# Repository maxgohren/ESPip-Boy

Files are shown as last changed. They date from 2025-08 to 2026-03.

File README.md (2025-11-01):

# ESPip-Boy
A smart watch based on the ESP32

# Features
* ESP32 MCU with full Bluetooth Classic
* SD Card storage
* TFT RGB Display
* Flashlight
* Microphone
* Sensors
  * Heart Rate & Blood Oxygen
  * Light Sensor (Auto Display Brightness)
  * Accelerometer (Auto Wakeup, Gestures) 
  * Magnetometer  (Compass)
* Controlled with Push-Button Rotary Encoder

# Planned Applications
* Compass
* Pedometer
* Map/Photo Display
* Clock
* Heart Rate Monitor
* Music Playback
* Bluetooth Manager
* System Monitor (CPU Tasks, SD Storage, RAM Usage etc.)

Powered by a LiPo, charged and programmed over USB

# V1.0 PCB Complete

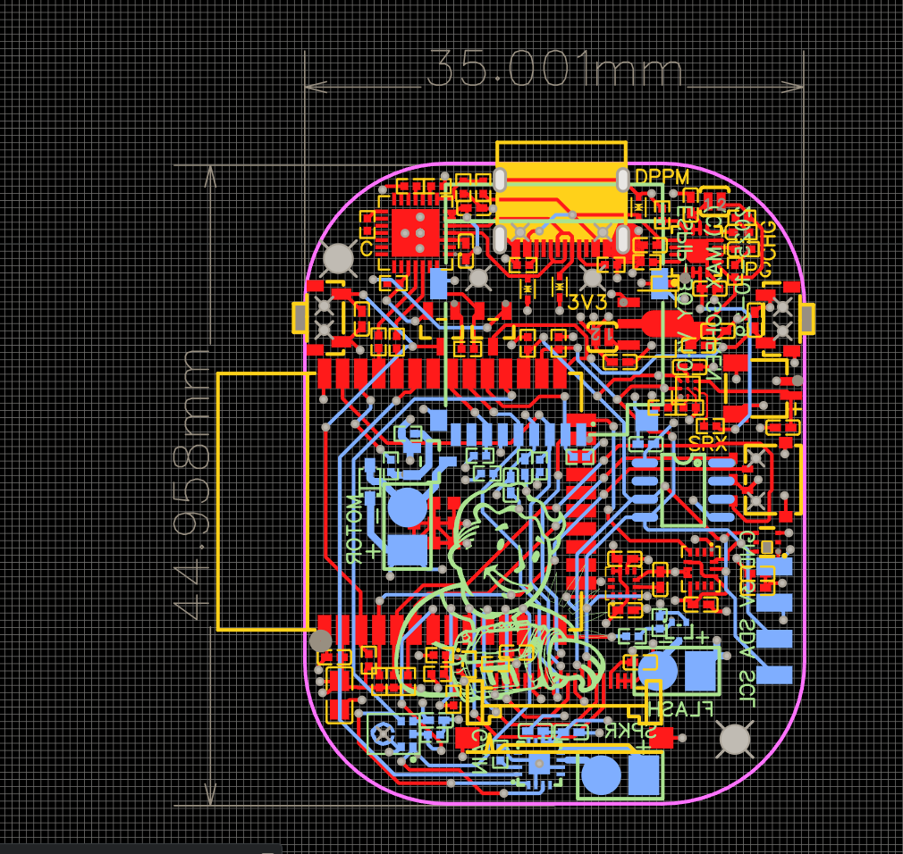
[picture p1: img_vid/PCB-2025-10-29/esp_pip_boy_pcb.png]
PCB Photo

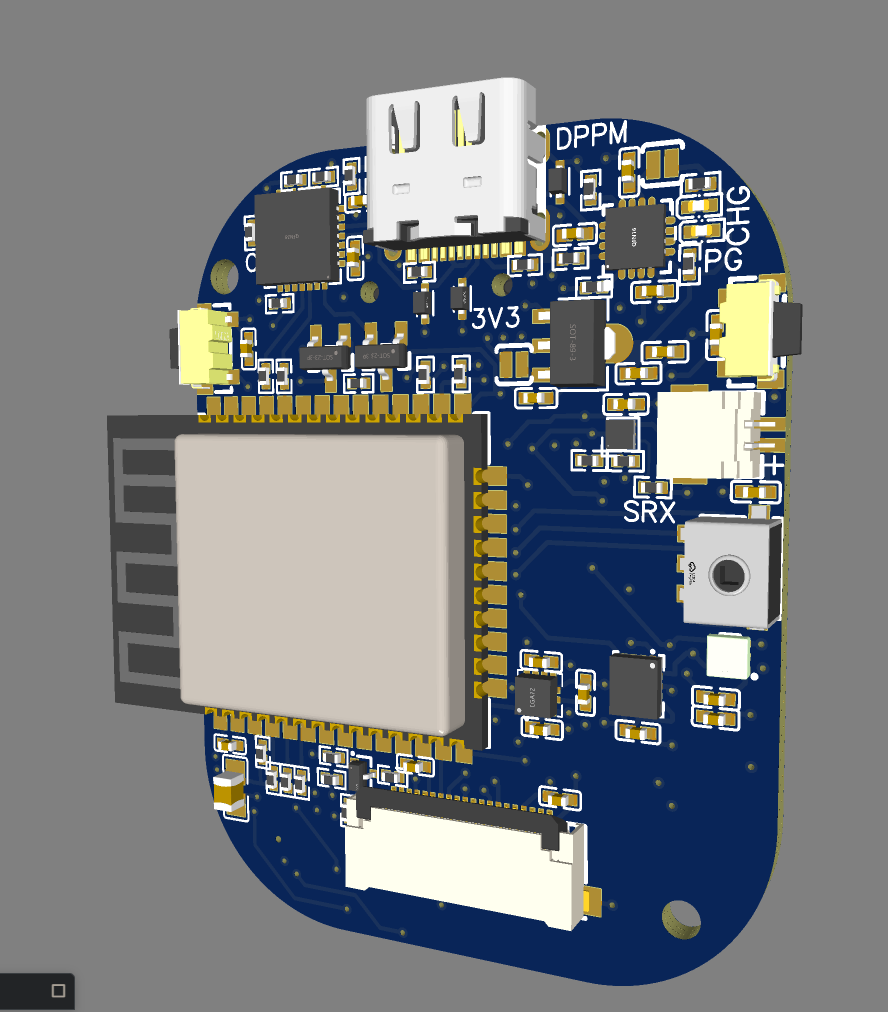
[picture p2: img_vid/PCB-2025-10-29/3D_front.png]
3D Front

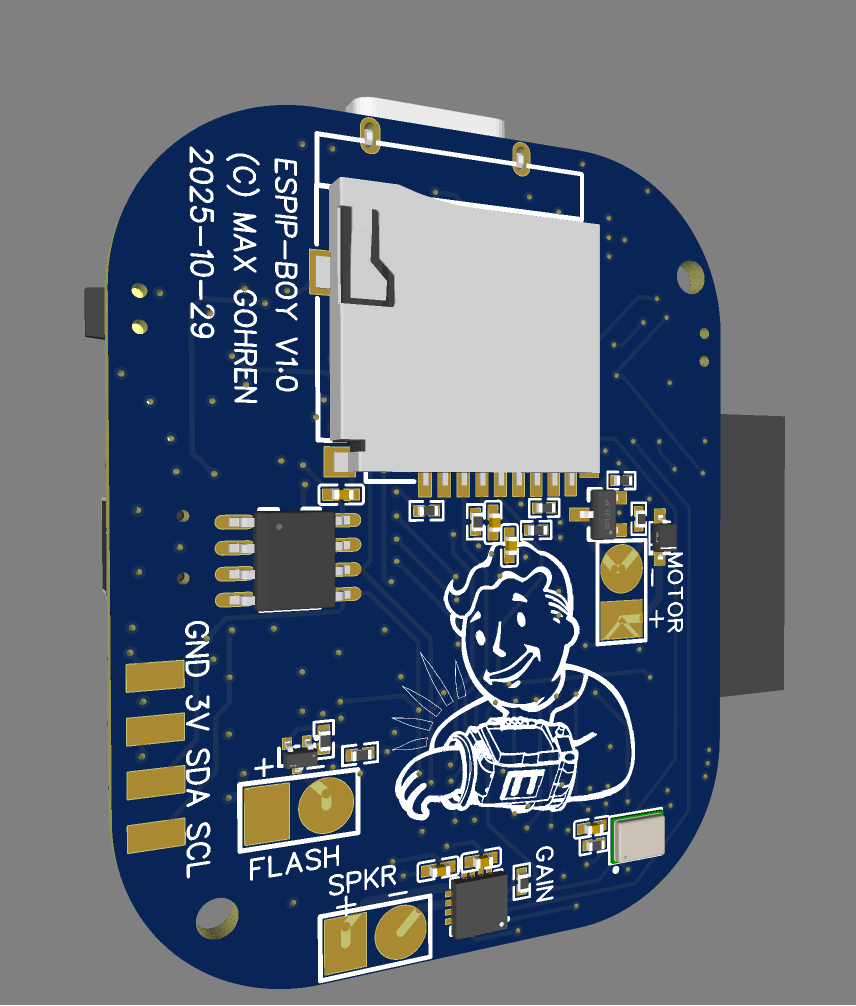
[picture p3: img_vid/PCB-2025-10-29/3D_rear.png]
3D Rear


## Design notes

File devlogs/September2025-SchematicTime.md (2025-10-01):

# September 30 2025 - Tuesday 11:41 PM
Audio recording works!

I've tried a handful of times on seperate occasions to record my microphone
output to a WAV file and write it to the SD Card. I've tried github examples,
built in examples and nothing has worked so far. I gave up on trying other
people's code, so I just got ChatGPT to write me the simplest example to do it.

Surprise surprise, it works great! And the code is so easy to understand,
organized in only one file so debugging is super easy. Other's used elaborate
wrappers on SD card libraries, made me use PlatformIO in VSCode, but never
actually got me a working product.

It is bittersweet though, it makes me feel as if I couldn't have done it
without ChatGPT. The truth is I can though, I would have ended up with
a similar solution anyways:
I would have taken the SD card library that has worked for me, and taken
Atomic14's I2S microphone example (which outputs just to the serial plotter), 
and combine them so that I have working mic + SD card. It is true I didn't do
this, and I haven't truly learned the I2S interface as well as I would like.

However, I can still, and I will, write my own implementation to at least
understand the calling of the different I2S functions, decrementing sample
counts and so on and so forth. 

Another development goal complete!

# September 25 2025 - Thursday  9:31 PM
Too many I2C devices!

0x15 -> CST816S Touchscreen Controller
0x19 -> LSM303 Accelerometer
0x1E -> HMC5883 Magnetometer
0x23 -> BH1750 Light Sensor

0x57 -> MAX30102 Heart Rate / Blood Oxygen Sensor
0x68 -> MPU6050 

0x57 -> DS3231 EEPROM Chip (AT24C32)
0x68 -> DS3231 RTC

Finally got the fake MAX17043 battery fuel gauge working, but it's terribly
wrong. Needed to ground the QST pin to get it recognized on the I2C bus, and
then got a reading of 12% when the battery had a voltage of ~3.7V haha. It's
easy enough to design around that I'm not concerned about not having it
working. 

I'm very excited, most of my prototyping is finished, and there are no more
parts I want to add. I've tested the USB input and charging the battery while
powering the load with the charger (I still may use the battery disconnect
circuit, it's only 2 components), and the microphone is working but I haven't
actually listened to the output yet. 

Almost done the breadboard prototype!
# September 24 2025 - Wednesday 10:43 PM
Got the speaker and the microphone working seperately again.

Speaker crackling issue? Was just the volume set too high! I turned it down the
audio was crystal clear at lower volumes, no crackling at all. Will have to
dial this in before production as gain is controlled through pulling the gain
pin high or low. 

The microphone is working again but confusing me. Using 
[atomic14's mic test](https://github.com/atomic14/esp32-i2s-mic-test/blob/main/README.md) I can only get the mic working when I use only the RIGHT channel of audio, even though I have the L/R pin pulled low. This confuses me as the [INMP441 datasheet](http://invensense.tdk.com/wp-content/uploads/2015/02/INMP441.pdf) says it only ooutputs to the right channel when the L/R pin is pulled low. Bizarre!

Now I am working on recording a sound clip to test the audio quality of the
microphone :).

# September 18 2025 - Thursday 12:16 AM
Got my audio equipment in today! A MAX98357 audio dac + amplifier combo (the IC
is so tiny haha) and a couple speakers, one I am currently trying is only 16
x 9 mm! And is quite loud!

I hooked it up and got some Gavin Adcock playing right away! It is very easy to
use, and I owe a huge thanks to [pschatzmann](https://github.com/pschatzmann),
his Arduino libraries are TOP NOTCH!

I do have a problem though, the audio is full of pops and crackle. I tried some
online troubleshooting which included adding some filtering caps at the power
supply, trying different power supplies, and changing the gain level, but
nothing seems to help. I am happy anyways to now have a working audio
interface, albeit a noisy one :).

# September 13 2025 - Saturday 11:44 AM
"It just works". It actually just works! LVGL with Arduino GFX + TouchLib
works! I still had to do the quirky include path editing and moving the demo
folder to make a demo work, but it works! No crazy colour bugs, no rotation
issues, no mismatch betwen coord systems between display and touch, it just
works!

I do have crashing on the button matrix, but a more complicated button matrix
with a scrolling view area works haha. I am very happy. The display is very
responsive and the LVGL grapics work just like they look on the examples. 

OMG the music player demo is sooo sick. The animations are actually pretty
smooth and the layout is perfect (aside from touchscreen bounds not being
dialed in, I can't exit a menu because the touchscreen bounds are smaller than
the drawn button bounds). 

Really satisfied with today's work and graphics setup. Really all there is to
do now, is implement a simple menu with one of the various widgets (and
hopefully one that doesn't crash) and then implement simple test apps for heart
rate, clock, etc. 

Then, when that is done, some sleep and interrupt handling on touch and motion. 

And then when our proof of concept is finished, were good to finalize the
design and properly finish the schematic, knowing the design works :).

https://github.com/user-attachments/assets/a17e04a2-b65c-40f8-9db9-b9d96eed87ed

# September 13 2025 - Saturday 12:54 AM
The new breadboard is off to an amazing start. All 6! i2C sensors enabled and
detected on i2c scan. Capacitive touch sensor working perfectly and very
responsively. Display working perfectly on test sketch. 

I am so happy it works. 20 pins later haha. I was scared to death too, because
I accidentally wired it up the wrong way after spending so long learning about
current limiting resistors and checking a million schematics to make sure
I wouldn't blow my backlight. Turns out I could smell how hot my touch
controller was, because I thought I was wiring up the display, but I was
actually wiring up the touch controller as my FPC breakout was flipped around.

I was using the silkscreen markings for the bottom side, not the side I was
actually connected to, on the 2 layer breakout board!

Even though my touch controller got super hot, I'm super happy it still works.
Here's to almost finishing a very clean prototype! Only a few more components
are in the mail, and then it's time to call it done, and start serious design
work on the PCB!

It was cleaner before the display

# September 11 2025 - Thursday 10:33 PM
Today I am taking a break from display software, to work on display hardware!

I got my new touchscreen TFT IPS display in, the same 1.69" I was using before
but not touchscreen. I am traumatized from my day spent with my resistive touch
2.4" and LVGL. 

I also got some new jumpers, breadboard and buck-boost power supply convertors
so my I actually ripped my whole breadboard clean and will rebuild it bigger,
better, faster, stronger in the coming days. My design is more finalized so
I figured it is time to clean it up to help in debugging and schematic design. 

I spent tonight tinkering with the new display and reading about backlight LED
current limiting resistors as I don't want to burn my only one out. If I do,
it's ok but I'd rather not wait another 2 weeks and another $12 for another
one. Looks like the reference schematics, my own model and some reading point
to resistors in the ~1-100 Ohm range, as the backlight drops 3.2V. For a 3.3V
supply, this leaves 0.1 V for the resistor. Limit it to 60 mA, gives you
a solid 1.7 Ohms, or a more conservative 40 mA for 2.5 Ohms. I'll use 10 and go
from there. 

Gonna take a break now. I have a habit of pouring so much time into this
project that it becomes stressful, with poor focus and fatigue being the
driving factors. I want more quality, less quantity. Looking forward to the new
display and the cleaner breadboard setup. Hopefully that inspires LVGL and my
touchscreen to work flawlessly together!

# September 10 2025 - Wednesday 11:47 PM
OMG LVGL is kind of a nightmare. 

I have been at it all day. Installing my touchscreen display, trying out more
examples and demos, finally comfortably using a slider widget, trying Arduino
IDE in WSL to improve horrendous build times, it's been the worst integration
into this project so far. 

The last headache (I hope it's the last) has been the touchscreen functionality
with TFT_eSPI and LVGL. I've found many threads complaing about how the
touchscreen seems to rotate completely opposite the display so it never lines up
correctly.

https://forum.lvgl.io/t/screen-rotation/19316/12
https://github.com/lvgl/lvgl/issues/7841
https://forum.lvgl.io/t/inconsistency-between-display-rotation-and-touchscreen-coordinate-rotation/20242

I've been trying solutions posted and playing with swapping coordinates around
but no success. I don't really understand what's happening under the hood, who
rotates what where, and how many times and which direction things are getting
rotated. I need to do some more experiments to see which rotations from which
libraries are required when. 

Thankfully I only need one orientation, I hope that may make this easier. But
man has this been a difficult ride.

# September 10 2025 - Wednesday 01:06 AM
Man LVGL is not simple to use. Manual install of folders to different locations
in the library. Copy the config to the libraries folder. Compile and get the
hello world running ok? Now try the demos, that in order to get it to just
barely work (it doesn't seem to respond to my choice of demo from the
		aformentioned config file) I need to manually massage a relative include
path of a header. WTF?

The one thing keeping me going right now is this demo of a smartwatch
[UI](https://lvgl.io/demos). It looks so amazing, I really hope I can get this
stable and working!

Time for bed now though, I am happy I got my demo working when this morning I
could only get the Hello World working.

# September  9 2025 - Tuesday 09:50 AM
Waiting for hardware. Stuck on power supply choices. Simple discrete components
linked together or a powerful PMIC with everything but the kitchen sink? I do
not like making schematics for components I don't have a working reference
design for right in front of me. I check JLC PCBA costs, and right out of the
gate my design, without any cost optimizations, will be $200 for two boards.
Pretty crazy.

I would then not like to experiment with new components I am not comfortable
with as this price drastically reduces the amount of hardware revisions I would
like to do. Instead, if I would like to use the cheap but ubiquitous AXP2101
with multiple bucks and LDOs, along with an integrated LiPo charger and fuel
gauge, I will order it on AliExpress along with a breakout board. This will
satisfy my need to have a working demo before I try to make a schematic
including it. 

It will be a parallel development/prototype with both a discrete setup (MAX17048
		Fuel Gauge + TP63020 buck-boost 3.3V supply + TP4056/DW01
		charger/protection) and an  integrated PMIC solution - AXP2101. Having a
working prototype will allow me to learn about the devices and have real world
measurements on how they perform in best and worst case battery life scenarios. 

No more endless document reading, get your hands dirty and see what works!

While waiting for the aformentioned hardware, I am working on LVGL integration.
It is the best solution for my graphic needs and looks amazing. I got the hello
world demo today, but man the examples/demo work is so annoying, they have this
requirement you copy the examples or demo folders into the src/ folder but it
always throws an error. It can't find the actual src, which according to the
include directives is in the place it would be if I never copied the demo folder
in the first place! So confusing, I will try again later!

# September  6 2025 - Saturday 12:36 AM
Today on my schematic, I wired up the display, the microphone and some roughed-in enable pins for
my various high power peripherals like my vibration motor, buzzer and speaker. I
did this so that I can see how many pins I have available and if my design is
going to all fit on the ESP32's GPIO selection. So far I think it will be okay,
and it will be helped if I can select a great PMIC with some I2C
selectable outputs. This would allow me to have more I2C control instead
of GPIO control which I am lacking. I really don't need the power of a
GPIO anyways for simple enable pins, but for stuff like vibration motors
or buzzers I do need a PWM output. All part of the balancing act haha.

I've asked ChatGPT a bunch of times for my perfect PMIC and it keeps
landing on the same modules, the MAX77658 and the TI BQ25190. Both are
great chips and both do what I need. I haven't yet narrowed it down, but I
would like to as it will influence the GPIO bottleneck and overall design.

I'm aiming at the following power path:
3.7V lipo -> buck boost @ 3.5V -> LDO @ 3.3V.
I'm weary of these PMICs and using the buck boost output to directly power my
ESP32 as the LDOs are more for the audio/RF paths, but I need the power spike
handling ability. I will read more about ripple and how the ESP32 handles it.

I'm really happy to have done more experimenting with the power supply and
found why I need what I need. Running the battery straight into the 3.3V
actually works and doesn't fry anything. This of course means my
aliexpress LDO is not rated high enough for the BT/WiFi spike. I would
like to try some bigger caps across the output to see if that helps. I've
got a big 220uF right here, but it's late.

I've made another order of parts like a buck-boost convertor, touch screen
and breadboard. I've also got a cart full of audio supplies like a MAX
mono amp and a small selection of tiny speakers. When these components
come in, I will (for the 15th time) be done prototyping haha. Well, I just
want it all working on a single board with all the devices connected so
that there are no suprises when the PCB comes in. I don't want to find out
theres another 500mA current spike somewhere and not have the hardware to
deal with it. 

LETSSS GOOOO!!!

# September  3 2025 - Wednesday  6:39 PM
It's been non-stop schematic time. Pouring over datasheets and reading
requirements to find the perfect components. I have almost finished this quest.
The last beast to slay, and the most important one, is the power management.
I want a complex system right now, and that may need to change:
* LiPo Battery Charging
* Battery Protection
* Battery Fuel Gauge
* Buck Convertor for ESP32 and display
* LDO for Audio and RF

I have found many suitable PMICs that have these requirements, but I am not
sure if I want to have this level of complexity. Part of me, just to keep it
simple, wants to do LiPo -> TP4056 -> 3.3V LDO -> power whole system. If
I can't decide or commit to a real PMIC, this discrete solution will work
perfectly fine :). Here's to knocking out the last of the part selection so
that the schematic can be finished and fine-tuned.

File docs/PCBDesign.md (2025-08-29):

# When finished assembly
* Check for shorts on all SMT components
* Check for shorts between chips and power rails
# Before Ordering
* No DRC errors of course
* Manully check each component and circuit on the board to make sure it was wired correctly
# USB
USB 2.0 spec defines a differential characteristic impedance of 90 ohms, +/- 15%.
[Controlled Impedance PCB Layer Stackup- JLCPCB](https://jlcpcb.com/impedance)
https://jlcpcb.com/pcb-impedance-calculator
https://docs.espressif.com/projects/esp-dev-kits/en/latest/esp32s3/esp32-s3-usb-bridge/user_guide.html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
https://dubiouscreations.com/2021/04/06/designing-with-usb-c-lessons-learned/
# Standard 
Changing all signal tracks to 6 mil for 60 Ohms, increasing space between tracks as well.
All power tracks not in polygons are 21 mil
# Copper Polygons
Surround power paths with copper fills (polygons) to lower resistance and give power an easier time to flow.
# Design Notes
* Start with an existing schematic and adapt it to your needs (like all learning)
* Thicker traces for power traces, thinner for signal
* Never go to minimum trace width/spacing -> you are increasing crosstalk
* Space traces 3 * tracewidth from each other
* Don't put silkscreen on vias or pads, it will not print on copper -> can tent vias to be able to print on them

## ESP32 Flash and PSRAM Design Guidelines
[PCB Layout Design - ESP32 - — ESP Hardware Design Guidelines latest documentation](https://docs.espressif.com/projects/esp-hardware-design-guidelines/en/latest/esp32/pcb-layout-design.html)
[esp32-sche-core.png (1602×816)](https://docs.espressif.com/projects/esp-hardware-design-guidelines/en/latest/esp32/_images/esp32-sche-core.png)
https://docs.espressif.com/projects/esp-hardware-design-guidelines/en/latest/esp32/schematic-checklist.html

# Notes on Battery + Power Circuit Design
https://www.best-microcontroller-projects.com/tp4056-page2.html
* TP4056 for charging of battery
* DW01 + Dual NMOSFET for overcharge and undercharge protection
* "LOAD SHARING": Final PMOSFET for disconnecting battery from load while charging: if load is still connected, it can throw off battery voltage readings

# Series Termination
Matching the impedance of the transmission line to improve signal quality

# Good PCB Design: 
* Working and Functional
* Signal Integrity
* EMI Performance
* IPC Standards Conformance
Submitting to Reddit r/PrintedCircuitBoard and Friends for Review
#### Sources
*Start with free resources before spending money*
Robert Federac
[How to Achieve Proper Grounding - Rick Hartley](https://www.youtube.com/watch?v=ySuUZEjARPY)
[PCB Design PDF](https://alternatezone.com/electronics/files/PCBDesignTutorialRevA.pdf)
#### Tools
[Saturn PCB Toolkit](https://saturnpcb.com/pcb_toolkit/)

#### Tutorials
[ESP32 Dev Board](https://www.youtube.com/watch?v=S_p0YV-JlfU&ab_channel=RobertFeranec)
[LiPo Battery Circuit](https://www.youtube.com/watch?v=Fj0XuYiE7HU&ab_channel=GreatScott%21)

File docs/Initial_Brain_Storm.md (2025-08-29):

# Inspiration
Here are some of the watches I've found on the internet that inspired me to build mine, or are currently influencing and helping the design due to their open source nature.
* Circuit Digest Smart Watch (The Original In[Making DIY Smart Watch with ESP32 - Designing Smart Watch Faces](https://circuitdigest.com/microcontroller-projects/designing-smartwatch-using-esp32)
* Bellafaire's ESP32 Smart Watch [Github](https://github.com/Bellafaire/ESP32-Smart-Watch)
* [ZSWatch]([https://github.com/ZSWatch/ZSWatch?tab=readme-ov-file#hardware)
*  [mike-rankin/ESP32-S3_1.69inch_Cap_Touch](https://github.com/mike-rankin/ESP32-S3_1.69inch_Cap_Touch)
#### 3D Printed Case
* Rough paint edges for a worn look!!! Super Sick! [Youtube](https://www.youtube.com/watch?v=l75A9TUMXOs&ab_channel=abe%27sprojects)
* Form Factor: DM99 Rectangular face smart watch
# Research Questions
## Straight up JARVIS Voice Control
1. 🟨Text-to-speech synthesizer? 
	* can definitely do, need a speaker but the audio will be robotic (low processing power)
2. 🟨Speech-to-text machine learning model? 
	* definitely not do on board (would be limited to YES or NO processing, would need to offload to a server with WIFI (doable -> use phone 5G even, or maybe on the phone itself?))
3. ✅ Microphone onboard
	* definitely doable
1. ✅ Speaker on board
## PCB Design and Assembly
1. What tools do I need?
		* Soldering Iron, solder
		* Hot plate for SMD, solder paste
2. What is a cost effective way to get electronic components, and how would it influence my design? 
	1. For example, can I use the same kinds of filtering capacitors all over my board or do different components have different requirements?
			* Yes you can
3. What are some absolute basic design principles to follow for a successful PCB? Test pads? Etc.
	* Test Pads
	* Trace width calculations adequate for expected current
	* Big Ground Plane
	* Via minimization
	* Good silkscreen with clear names and organization of parts (don't put on vias!)
	* Design Rules Checker
4. What are some advanced design features to ensure a successful PCB?
# Design Goals
* Wearable smart watch
* LED Flashlight
* GPS Module with loadable maps and GPS app
* Music storage and playback via Bluetooth
* Learn about PCB Design
	* Trace length
	* High speed traces and interference
		* SD Card reading
		* USB input
# Build Guide
[Circuit Digest](https://circuitdigest.com/microcontroller-projects/diy-smartwatch-using-esp32-part3-interfacing-magnetometer-and-gyroscope-with-esp32)
# Hardware

	#### LiPo Battery Circuit
* TP4056 battery charging circuit
* USB input
* DW01 protection circuit
	* Discharge and Overvoltage protection
	* Requires 2 Dual-Channel N-type MOSFETs from FS8205
* What voltages do I need for all my components?
	* Do I need boost convertors to increase the voltage to 5V?
	*  Definitely need LDO for dropping voltage down to 3.3V or 1.8V
#### ESP32 MCU
* Dual core allows for music playback
### Display
1.69" 240x280 pixel TFT LCD display
2.4" 320x240 capacitive touch TFT LCD Display
**FPC connector** for plugging in display instead of soldering
### Controls
* EC11 Rotary Encoder with Button
* 2 Buttons
### Storage
* SD Card Adapter for storage of Maps and Music
### Flashlight
RBG LED w/ heatsink and power supply?
### Laser BEAM!?
### Sensors
#### BN180 GPS Module
#### LSM303DLHC Accel/Magnetometer OR MPU6050 Accelerometer + QMC5883L Magnetometer
for tracking steps
auto wakeup
Triple Axis Magnetometer for Compass

| IMU Chip | Axes | Extra features | Notes |
| --- | --- | --- | --- |
| **MPU-6050** (InvenSense) | 6 | Simple accel+gyro, cheap (~\$2), no magnetometer | Old, needs external processing for gestures. |
| **MPU-9250** / **ICM-20948** (InvenSense/TDK) | 9 | Has DMP, can output orientation, tap detection | More expensive (~\$6-10) |
| **LSM6DSOX** (STMicro) | 6 | Built-in machine learning core for gesture classification in hardware | Great for ultra-low-power wearables, supports wrist tilt, pickup. |
| **BNO055** (Bosch) | 9 | Built-in sensor fusion/calibration | Simple but more power hungry. |
| **BMI270 + BMM150** (Bosch) | 6 + 3  | BMI270 = 6-axis with gesture/tap detection, BMM150 = magnetometer | Can be paired if needed. |
| **LIS3DH / LSM6DSL** (STMicro)<br> | 3 or 6 | Basic motion detection | Common in low-end wearables. |
| | | | |
| | | | |
| | | | |
ChatGPT recommends LSM6DSOX as it has a built in ML core for gesture detection. That would be really cool and low power. 
I can then throw on a cheap magnetometer like the LSM6DSL for my compass app!
LGA is a pain in the ass, might have to get it assembled by PCB manufacturer.
Could also do MLC for MPU6050 in python library.

#### BH1750 Light Sensor
Change display brightness based on ambient light
#### MAX30102 Heart Rate / Blood Oxygen Sensor

# Software
## OS
* FreeRTOS
* NuttX
### Applications
* Local music player over bluetooth
* GPS app with user-uploadable maps via USB
* Main Display app with configurable nodes
	* Clock
	* Temperature / Humidity
	* Heartbeat
	* Compass
* Resource Monitor App
	* Battery
	* CPU -> only task count is available, CPU usage is not like traditional PCs due to different task scheduling
	* RAM
	* SD Card storage

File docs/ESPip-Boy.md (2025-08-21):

# Inspiration
https://github.com/Bellafaire/ESP32-Smart-Watch
[Making DIY Smart Watch with ESP32 - Designing Smart Watch Faces](https://circuitdigest.com/microcontroller-projects/designing-smartwatch-using-esp32)
# Research Questions
## Straight up JARVIS Voice Control
1. 🟨Text-to-speech synthesizer? 
	* can definitely do, need a speaker but the audio will be robotic (low processing power)
2. 🟨Speech-to-text machine learning model? 
	* definitely not do on board (would be limited to YES or NO processing, would need to offload to a server with WIFI (doable -> use phone 5G even, or maybe on the phone itself?))
3. ✅ Microphone onboard
	* definitely doable
1. ✅ Speaker on board

## PCB Design and Assembly
1. What tools do I need?
		* Soldering Iron, solder
		* Hot plate for SMD, solder paste
1. What is a cost effective way to get electronic components, and how would it influence my design? 
	1. For example, can I use the same kinds of filtering capacitors all over my board or do different components have different requirements?
			* Yes you can
1. What are some absolute basic design principles to follow for a successful PCB? Test pads? Etc.
	* Test Pads
	* Trace width calculations adequate for expected current
	* Big Ground Plane
	* Via minimization
	* Good silkscreen with clear names and organization of parts (don't put on vias!)
	* Design Rules Checker
1. What are some advanced design features to ensure a successful PCB?

# Design Goals
* Wearable smart watch
* LED Flashlight
* GPS Module with loadable maps and GPS app
* Music storage and playback via Bluetooth
* Learn about PCB Design
	* Trace length
	* High speed traces and interference
		* SD Card reading
		* USB input

# Build Guide
[Circuit Digest](https://circuitdigest.com/microcontroller-projects/diy-smartwatch-using-esp32-part3-interfacing-magnetometer-and-gyroscope-with-esp32)
# Hardware

	#### LiPo Battery Circuit
* TP4056 battery charging circuit
* USB input
* DW01 protection circuit
	* Discharge and Overvoltage protection
	* Requires 2 Dual-Channel N-type MOSFETs from FS8205
* What voltages do I need for all my components?
	* Do I need boost convertors to increase the voltage to 5V?
	*  Definitely need LDO for dropping voltage down to 3.3V or 1.8V
#### ESP32 MCU
* Dual core allows for music playback
### Display
1.69" 240x280 pixel TFT LCD display
2.4" 320x240 capacitive touch TFT LCD Display
**FPC connector** for plugging in display instead of soldering
### Controls
* EC11 Rotary Encoder with Button
* 2 Buttons
### Storage
* SD Card Adapter for storage of Maps and Music
### Flashlight
RBG LED w/ heatsink and power supply?
### Laser BEAM!?
### Sensors
#### BN180 GPS Module
#### LSM303DLHC Accel/Magnetometer OR MPU6050 Accelerometer + QMC5883L Magnetometer
for tracking steps
auto wakeup
Triple Axis Magnetometer for Compass

| IMU Chip | Axes | Extra features | Notes |
| --- | --- | --- | --- |
| **MPU-6050** (InvenSense) | 6 | Simple accel+gyro, cheap (~\$2), no magnetometer | Old, needs external processing for gestures. |
| **MPU-9250** / **ICM-20948** (InvenSense/TDK) | 9 | Has DMP, can output orientation, tap detection | More expensive (~\$6-10) |
| **LSM6DSOX** (STMicro) | 6 | Built-in machine learning core for gesture classification in hardware | Great for ultra-low-power wearables, supports wrist tilt, pickup. |
| **BNO055** (Bosch) | 9 | Built-in sensor fusion/calibration | Simple but more power hungry. |
| **BMI270 + BMM150** (Bosch) | 6 + 3  | BMI270 = 6-axis with gesture/tap detection, BMM150 = magnetometer | Can be paired if needed. |
| **LIS3DH / LSM6DSL** (STMicro)<br> | 3 or 6 | Basic motion detection | Common in low-end wearables. |
| | | | |
| | | | |
| | | | |
ChatGPT recommends LSM6DSOX as it has a built in ML core for gesture detection. That would be really cool and low power. 
I can then throw on a cheap magnetometer like the LSM6DSL for my compass app!
LGA is a pain in the ass, might have to get it assembled by PCB manufacturer.
Could also do MLC for MPU6050 in python library.

#### BH1750 Light Sensor
Change display brightness based on ambient light
#### MAX30102 Heart Rate / Blood Oxygen Sensor

#### 3D Printed Case
Design Inspo -> rough paint edges for a worn look!!! Super Sick! 
https://www.youtube.com/watch?v=l75A9TUMXOs&ab_channel=abe%27sprojects

Form Factor inspo DM99 Rectangular face smart watch
Maybe offset the strap?
![[Pasted image 20250714144210.png]]

# Software
## OS
* FreeRTOS
* NuttX

### Applications
* Local music player over bluetooth
* GPS app with user-uploadable maps via USB
* Main Display app with configurable nodes
	* Clock
	* Temperature / Humidity
	* Heartbeat
	* Compass
* Resource Monitor App
	* Battery
	* CPU -> only task count is available, CPU usage is not like traditional PCs due to different task scheduling
	* RAM
	* SD Card storage

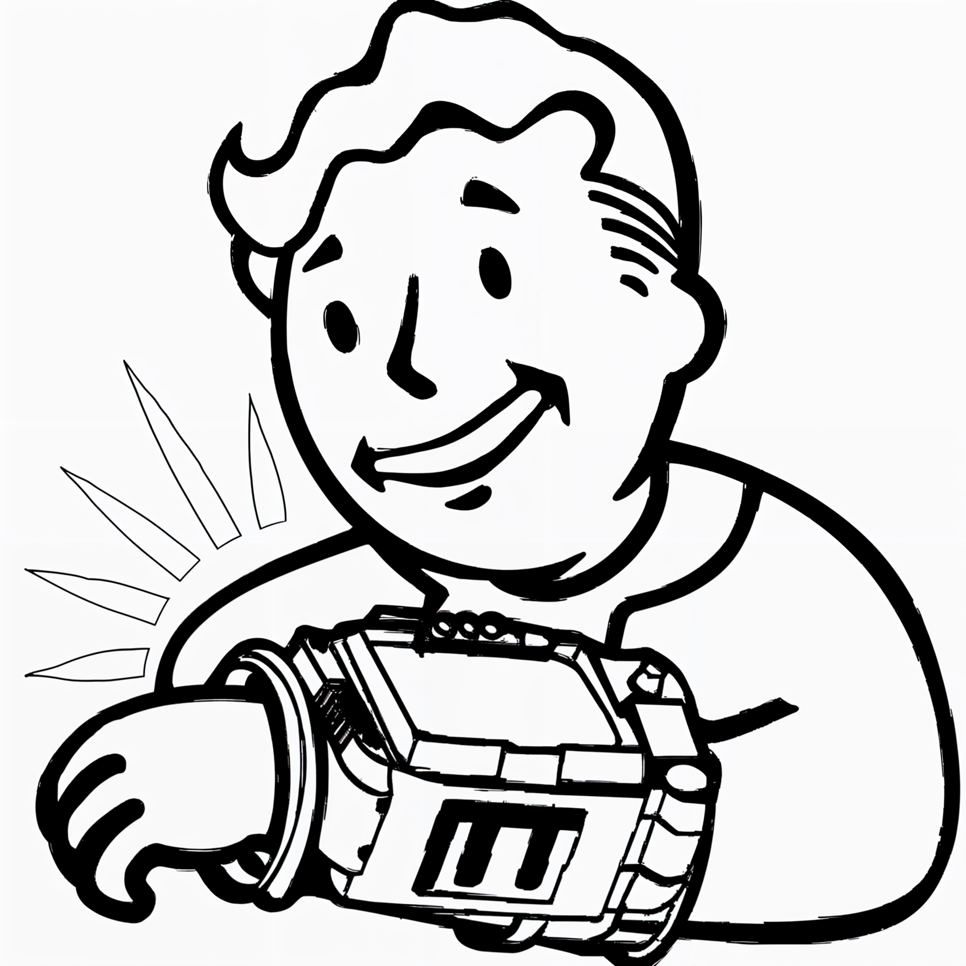
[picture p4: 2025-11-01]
img_vid/PCB-2025-10-29/silkscreen.png

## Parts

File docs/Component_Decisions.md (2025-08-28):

It's time to decide concretely about components for my watch. Without this list, I will be stuck in prototyping stage forever! Time to choose the best option and commit!

# Final Decisions For Schematic

| Component | Name | Cost | Size | Voltage | Current Draw | Feature It Enables | Datasheet | Design Reference |
| --- | --- | --- | --- | --- | --- | --- | --- | --- |
| MCU | ESP32-WROOM-32E-16  | | 18x25.5mm for PCB ant.<br>18x19.2mm for UFL connector | | | Wifi NTP time, Wifi Fileserver<br>BT music playback<br> | | |
| GPS | Quectel L96 | $20<br> | | 3.3V Supply<br>2.8V IO | | | | |
| Accelerometer + Gyroscope | Bosch BMI270 | | | | | * Gestures<br>* Wake up display<br>* Pedometer | | |
| Magnetometer | ST LIS2MDL | | | | 0.2mA | Compass | https://www.lcsc.com/datasheet/C919695.pdf | |
| Ambient Light Sensor | BH1750 | | | 3.3V | | Display brightness control | https://www.lcsc.com/product-detail/C78960.html | |
| Heart Rate Sensor | MAXIM MAX30101EFD+T | $7.82 | | 1.8V, need small LDO<br>3.3V LED | 1mA | | https://www.lcsc.com/product-detail/C2859066.html | |
| Microphone | | | | | | Voice Note app | | |
| Vibration Motor | | | | | | Vibrate on notification | https://www.lcsc.com/product-detail/C2759984.html | |
| Vibration Motor Driver | TI DRV2605 | | | | | | https://www.ti.com/lit/ds/symlink/drv2605.pdf | |
| | | | | | | | | |
| | | | | | | | | |
| | | | | | | | | |
# Goofy Extras To Think About
From ZSWatch: BME688 gas sensor https://www.bosch-sensortec.com/products/environmental-sensors/gas-sensors/bme688/#applications
altitude/pressure sensor https://www.bosch-sensortec.com/products/environmental-sensors/pressure-sensors/bmp581/

shitty speaker? https://www.lcsc.com/product-detail/C30587345.html
# ZSWATCH - Great design inspo and small form factor
https://github.com/ZSWatch/ZSWatch/blob/main/resources/images/Hardware-Overview.png

# Motor Notes
Vybronics https://www.digikey.ca/en/products/detail/vybronics-inc/VG0832022D/9974288
LRA is linear resonance, need haptic driver to maintain PWM and offload from main cpu, provides tight haptic feedback for touch
eccentric rotating mass is cheaper and easier to drive, but mushier
# External PSRAM
https://docs.espressif.com/projects/esp-idf/en/stable/esp32/api-guides/external-ram.html
#  UI Control
### Micro Rotary Encoder
We can't use the EC11 it's monstrous, honestly they all are...
[9.5mm ec11](https://www.aliexpress.com/item/1005008519804850.html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)
[Mouse wheel encoder](https://www.aliexpress.com/item/32360048492.html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,scm-url:1007.40050.354490.0,pvid:b4653ad8-7c58-496e-a97d-fb6d39e69a61,tpp_buckets:668%232846%238110%231995&isseo=y&pdp_ext_f=%7B%22order%22%3A%22142%22%2C%22eval%22%3A%221%22%2C%22sceneId%22%3A%2230050%22%7D&pdp_npi=6%40dis%21CAD%212.76%212.40%21%21%211.95%211.70%21%402101effb17561751372727582ef282%2112000017941569939%21rec%21CA%21895251878%21X%211%210%21n_tag%3A-29919%3Bd%3Afbd1bb7%3Bm03_new_user%3A-29895%3BpisId%3A5000000179765277&utparam-url=scene%3ApcDetailBottomMoreOtherSeller%7Cquery_from%3A%7Cx_object_id%3A32360048492%7C_p_origin_prod%3A)
[up down and press switch](https://www.aliexpress.com/item/4000697123862.html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,scm-url:1007.40050.354490.0,pvid:b4653ad8-7c58-496e-a97d-fb6d39e69a61,tpp_buckets:668%232846%238110%231995&isseo=y&pdp_ext_f=%7B%22order%22%3A%22344%22%2C%22eval%22%3A%221%22%2C%22sceneId%22%3A%2230050%22%7D&pdp_npi=6%40dis%21CAD%212.85%212.74%21%21%212.01%211.93%21%402101effb17561751372727582ef282%2110000006104988133%21rec%21CA%21895251878%21X%211%210%21n_tag%3A-29919%3Bd%3Afbd1bb7%3Bm03_new_user%3A-29895&utparam-url=scene%3ApcDetailBottomMoreOtherSeller%7Cquery_from%3A%7Cx_object_id%3A4000697123862%7C_p_origin_prod%3A)
### Touchscreen
Need touchscreen display but I've always wanted one
### Buttons 
2 pins for 2 buttons or matrix of 4 buttons with still just 2 pins, very effective

### Joysticks
5 button control, Left-Right-Up-Down-Middle, lots of pins and medium size

# Power Management IC

| MAKE | MODEL | Price | Single Cell Charger ✅ | Fuel Guage ✅ | Battery Protector ✅ | 300 mAh Buck Regulator  ✅ | Power Button Reset | Link |
| --- | --- | ----- | --- | --- | --- | --- | --- | --- |
| PERFECT | | | | | | | | |
| MAXIM | MAX17332 | $10 | 500 mAh | Percent, Capacity<br>Time-to-Empty/Full<br>Age • Cycle+™ Age Forecast  <br>Age-Scheduled Charging | Overvoltage/Overcharge Current<br>• Temperature Region Dependent <br>• Overcharge/Discharge/Short-Circuit Current <br>• Over/Under Temperature • Zero-Volt or >1.8V Charging Option<br>• Undervoltage + SmartEmpty | NO! | | [1](https://www.digikey.ca/en/products/detail/analog-devices-inc-maxim-integrated/MAX17332X22-T/21412976) |
| Analog Devices | ADP5360 | $10 | | | 2.8V under voltage -> is this high enough? | YES! | | [Digikey](https://www.digikey.ca/en/products/detail/analog-devices-inc/ADP5360ACBZ-2-R7/14562510) |
| MAXIM | MAX77650 + MAX17055 | | | | | | | |
| Texas Instruments | TI modular stack (bq2512x + bq27xxx + protector) | | | | | | | |

https://www.electronicsforu.com/electronics-projects/gsm-gps-module-diy

# GNSS Module - Quectel L96
GNSS Const. : 1 - GPS, 2 - Galileo, 3 - GLONASS, 4 - Beidou

https://stuartsprojects.github.io/2020/09/10/GPS-antennas-effectiveness-and-weight.html

### Product Comparison

| Make | Model | GNSS Const. | Price | VIN  | V Logic | Antenna | Install<br>Difficulty | Datasheet | Purchase | HW  |
| --- | --- | --- | ----- | ---- | --- | --- | --- | --- | --- | --- |
| PERFECT  | THING | 1234 | ~$15  | 3.3V | 3.3V | PCB / Patch | | | | |
| uBlox | CAM-M8Q-0 | 1234 | $45 | 3.3V | 3.3V | PCB | Med. | [Data](https://www.mouser.ca/datasheet/2/1025/CAM_M8_FW3_DataSheet__UBX_15031574_-3180405.pdf) | [1](https://www.mouser.ca/ProductDetail/u-blox/CAM-M8Q-0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) | |
| Quectel  | L76 | | | | | | | | | |
| | L86G-AA (AA has <br>smaller antenna | 1234 | $15 | 3.3V | 3.3V | Patch | Easy, but has LGA GND pins underneath | [Data](https://mm.digikey.com/Volume0/opasdata/d220001/medias/docus/7133/Quectel_LC86G_Series_GNSS_Specification_V1.4.pdf) | [Digikey](https://www.digikey.ca/en/products/detail/quectel/LC86GAAMD/16719586) | |
| | L96 | | $20 | 3.3V | 2.8V | | Easy, only need | [DS](https://auroraevernet.ru/upload/iblock/36c/36c11c043ed14557903899eb54fc4657.pdf)[Hardware](https://www.sigmaelectronica.net/wp-content/uploads/2024/07/quectel_lc86g_series_hardware_design_v1-1.pdf) | [Digikey](https://www.digikey.ca/en/products/detail/quectel/L96-M33/13278244) | |
| Antenova | M20072 | 1234 | $30 | 1.8V | 1.8V | PCB | Med. -> 1.8V logic and matching antenna | [1](https://www.mouser.ca/datasheet/2/23/M20072_PS_1_01-3104216.pdf) | [1](https://www.mouser.ca/ProductDetail/Antenova/M20072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) | |
| YIC | YIC31616GMSGG | 12 | $16 | 3.3V | | | Easy | | [1](https://www.digikey.ca/en/products/detail/yic/YIC31616GMSGG/21804294) | |
| Beitian  | 180 | | | | | | | | | |
| Beitain  | 122 | $15 | | | | | | | [1](https://www.aliexpress.com/item/1005006125395486.html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) | |
| | | | | | | | | | | |
### Logic Shifters - Don't Need
* Recommended over simple resistor voltage dividers (uses amplifying transistors)
* Can shift up and down, can't shift up from 1.8V -> 3.3V with resistors (would have to rely on ESP32 reading 1.8V as positive value)
	* Logic high: 0.7 * VDD -> 0.7 * 3.3V = 2.31V :(
* Simple logic shifter is array of transistors [SparkFun 4$](https://learn.sparkfun.com/tutorials/bi-directional-logic-level-converter-hookup-guide/all) [Thread](https://forum.arduino.cc/t/uart-communication-between-3-3v-and-1-8v-logic-level/1193454/9)
* [Philips Application Note for Logic Shifters](https://cdn.sparkfun.com/tutorialimages/BD-LogicLevelConverter/an97055.pdf)
* L96 says you can just use voltage divider for logic shifting (3.3 -> 2.8V)

# ESPRESSIF ESP32-WROOM-32E-N16 
Only a couple dollars for the 16MB flash version compared to the 4MB flash version, lets do it! 
### PCB Antenna or U.FL connector?
* [$3 UFL Antenna](https://www.digikey.ca/en/products/detail/sparkfun-electronics/18086/14313956) 
	* Can use this to integrate to wristband?
* PCB I think will be larger compared to a UFL in a 
https://www.lcsc.com/product-detail/C701346.html?s_z=n_ESPRESSIF%2520ESP32-WROOM
https://www.lcsc.com/product-detail/C5361945.html?s_z=n_ESPRESSIF%2520ESP32-WROOM-32E

# Microphone
The hole is on the bottom! Mount it underneath!

| | Freq Response<br> | Current Consumption | Voltage | Low Power Mode | Interface | Size | Mic Position |
| --- | --- | --- | --- | --- | --- | --- | --- |
| INMP444 | 60 - 15kHz | 2.5mA at 3.3V | 3.3V max 3.6V | Standby 0.8 mA | I2S | 4.72 x 3.76 x 1 mm | Bottom |
| ICS-43434 | 60 Hz - 20kHz | 550 uA at 1.8V | 3.3V<br>MAX 3.6V | Yes<br>300 uA at 1.8V | I2S | 3.50 mm x 2.65mm x 0.98mm | Bottom |
How does bottom positioning work? Should it be placed underneath the PCB so the mic hole faces the user?
* I believe so, I will test with my module when it arrives. Looks like it is mounted underneath

# Total Purchases so Far

$60 - initial Aliexpress order
$43 - second Aliexpress Order
$35 - duty for Antenova 'free' samples haahah
$20 - hot plate
$37 - Hot air gun

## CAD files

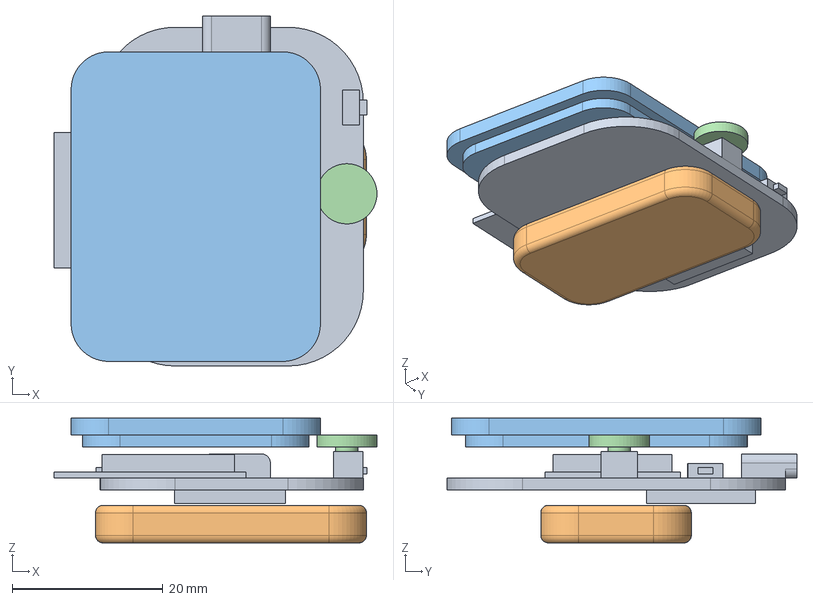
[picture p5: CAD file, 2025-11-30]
hardware/case/assembly_espip-boy.FCStd
42.9 x 46.5 x 16.6 mm
pcb_espip-boy_001
battery_espip-boy_001
display_espip-boy_001
encoder_knob_espip-boy_001

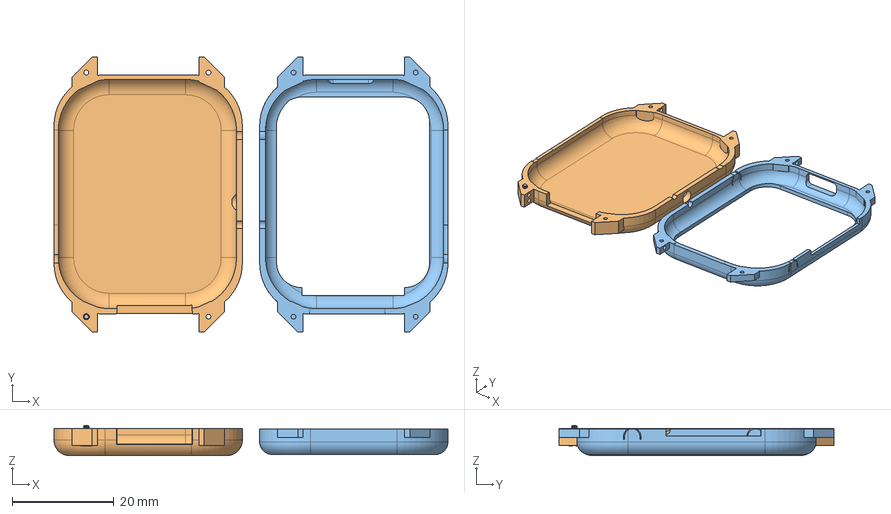
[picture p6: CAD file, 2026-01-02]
hardware/case/v2/case_less_pcb_components.FCStd
77.4 x 54.0 x 5.90 mm
M1.2 Screw
Slice.0
Slice.1

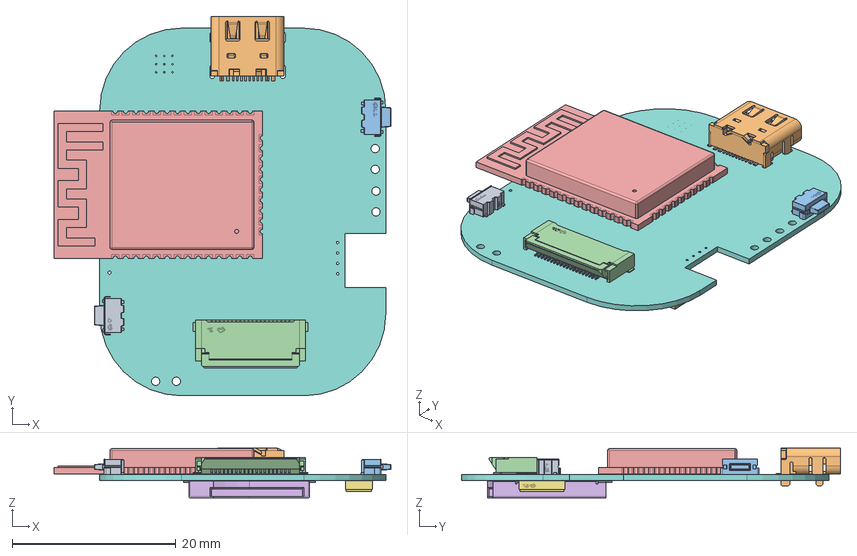
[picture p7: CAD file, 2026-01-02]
hardware/easyeda_pcb_to_kicad/pcb_rev2_less_components.FCStd
41.2 x 46.4 x 6.09 mm
SW-SMD_L4.7-W3.5-H1.9-P3.35-EH
USB-C-SMD_G-SWITCH_GT-USB-7010ASV
SW-SMD_L4.7-W3.5-H1.9-P3.35-EH001
FPC-SMD_20P-P0.50_L13.5-W5.9-H2.0-XF2M-2015-1A
ESP32-WROOM-32E
TF-SMD_TF-PUSH
OESIP-14_L5.6-W3.3-P0.80-TL
espip_boy_rev2_PCB

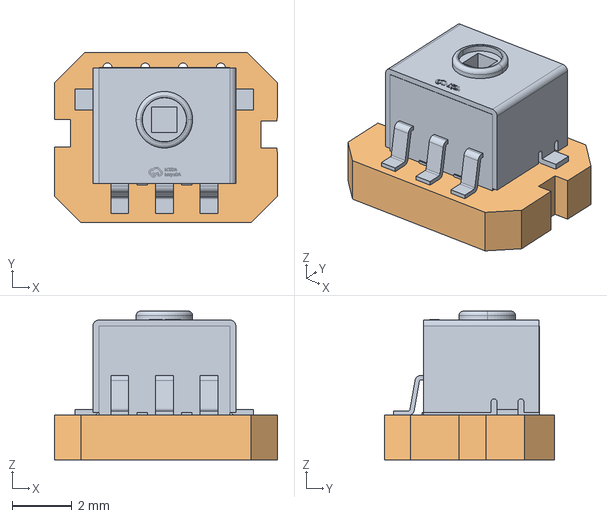
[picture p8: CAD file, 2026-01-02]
hardware/pcb_digital_crown/digital_crown.FCStd
7.49 x 5.72 x 5.00 mm
RES-ADJ-SMD_GT-EVA01AA-L1
BackupProjects_mgohren_personal_1_20251228_PCB

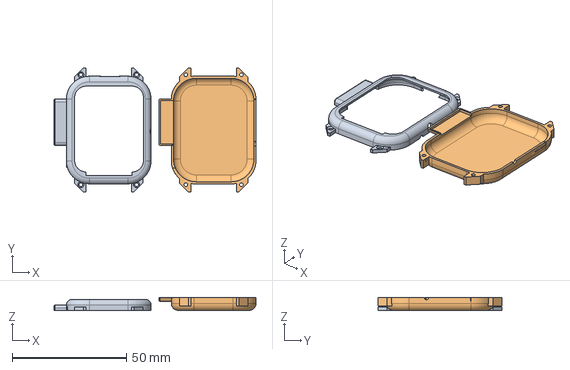
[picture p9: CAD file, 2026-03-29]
hardware/case/V3_case.FCStd
88.2 x 54.2 x 5.56 mm
OhYeahToop
Bot

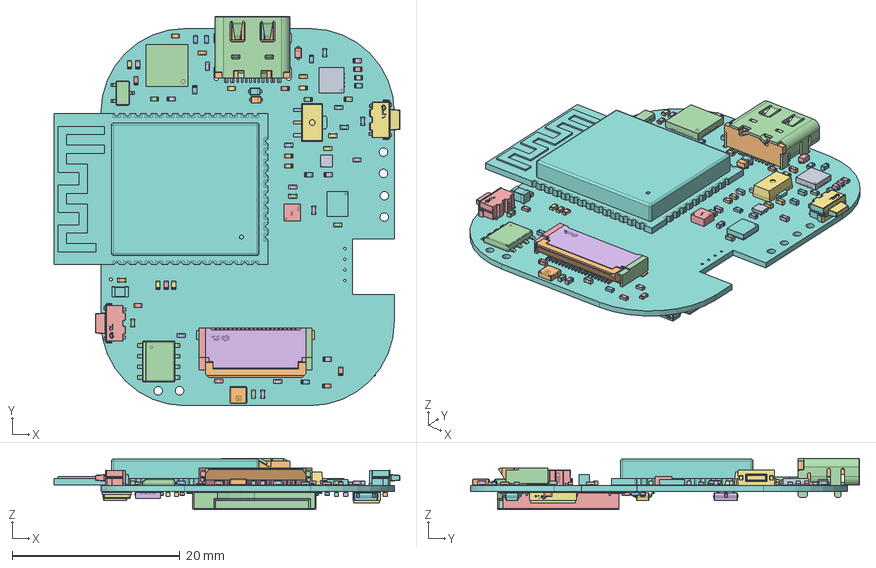
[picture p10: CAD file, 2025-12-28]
hardware/easyeda_pcb_to_kicad/pcb_rev2.FCStd
41.3 x 46.4 x 6.09 mm
C_0402_1005Metric
R_0402_1005Metric
SW-SMD_L4.7-W3.5-H1.9-P3.35-EH
SW-SMD_L4.7-W3.5-H1.9-P3.35-EH001
SW-SMD_L4.7-W3.5-H1.9-P3.35-EH002
SW-SMD_L4.7-W3.5-H1.9-P3.35-EH003
SW-SMD_L4.7-W3.5-H1.9-P3.35-EH004
SW-SMD_L4.7-W3.5-H1.9-P3.35-EH005
SW-SMD_L4.7-W3.5-H1.9-P3.35-EH006
SW-SMD_L4.7-W3.5-H1.9-P3.35-EH007
SW-SMD_L4.7-W3.5-H1.9-P3.35-EH008
SW-SMD_L4.7-W3.5-H1.9-P3.35-EH009
SW-SMD_L4.7-W3.5-H1.9-P3.35-EH010
SW-SMD_L4.7-W3.5-H1.9-P3.35-EH011
SW-SMD_L4.7-W3.5-H1.9-P3.35-EH012
SW-SMD_L4.7-W3.5-H1.9-P3.35-EH013
SW-SMD_L4.7-W3.5-H1.9-P3.35-EH014
SW-SMD_L4.7-W3.5-H1.9-P3.35-EH015
C_0402_1005Metric001
QFN-28-1EP_5x5mm_P0.5mm_EP3.35x3.35mm
R_0402_1005Metric001
C_0402_1005Metric002
R_0402_1005Metric002
C_0805_2012Metric
R_0402_1005Metric003
SENSOR-SMD_LTR-390UV-01
R_0402_1005Metric004
R_0402_1005Metric005
C_0402_1005Metric003
R_0402_1005Metric006
DSBGA-9_L1.5-W1.5-H0.6-R3-C3-P0.50-BL
DSBGA-9_L1.5-W1.5-H0.6-R3-C3-P0.50-BL001
DSBGA-9_L1.5-W1.5-H0.6-R3-C3-P0.50-BL002
DSBGA-9_L1.5-W1.5-H0.6-R3-C3-P0.50-BL003
DSBGA-9_L1.5-W1.5-H0.6-R3-C3-P0.50-BL004
DSBGA-9_L1.5-W1.5-H0.6-R3-C3-P0.50-BL005
DSBGA-9_L1.5-W1.5-H0.6-R3-C3-P0.50-BL006
DSBGA-9_L1.5-W1.5-H0.6-R3-C3-P0.50-BL007
DSBGA-9_L1.5-W1.5-H0.6-R3-C3-P0.50-BL008
DSBGA-9_L1.5-W1.5-H0.6-R3-C3-P0.50-BL009
DSBGA-9_L1.5-W1.5-H0.6-R3-C3-P0.50-BL010
R_0402_1005Metric007
R_0402_1005Metric008
C_0402_1005Metric004
R_0402_1005Metric009
USB-C-SMD_G-SWITCH_GT-USB-7010ASV
USB-C-SMD_G-SWITCH_GT-USB-7010ASV001
USB-C-SMD_G-SWITCH_GT-USB-7010ASV002
USB-C-SMD_G-SWITCH_GT-USB-7010ASV003
USB-C-SMD_G-SWITCH_GT-USB-7010ASV004
USB-C-SMD_G-SWITCH_GT-USB-7010ASV005
USB-C-SMD_G-SWITCH_GT-USB-7010ASV006
USB-C-SMD_G-SWITCH_GT-USB-7010ASV007
USB-C-SMD_G-SWITCH_GT-USB-7010ASV008
USB-C-SMD_G-SWITCH_GT-USB-7010ASV009
USB-C-SMD_G-SWITCH_GT-USB-7010ASV010
USB-C-SMD_G-SWITCH_GT-USB-7010ASV011
USB-C-SMD_G-SWITCH_GT-USB-7010ASV012
USB-C-SMD_G-SWITCH_GT-USB-7010ASV013
USB-C-SMD_G-SWITCH_GT-USB-7010ASV014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

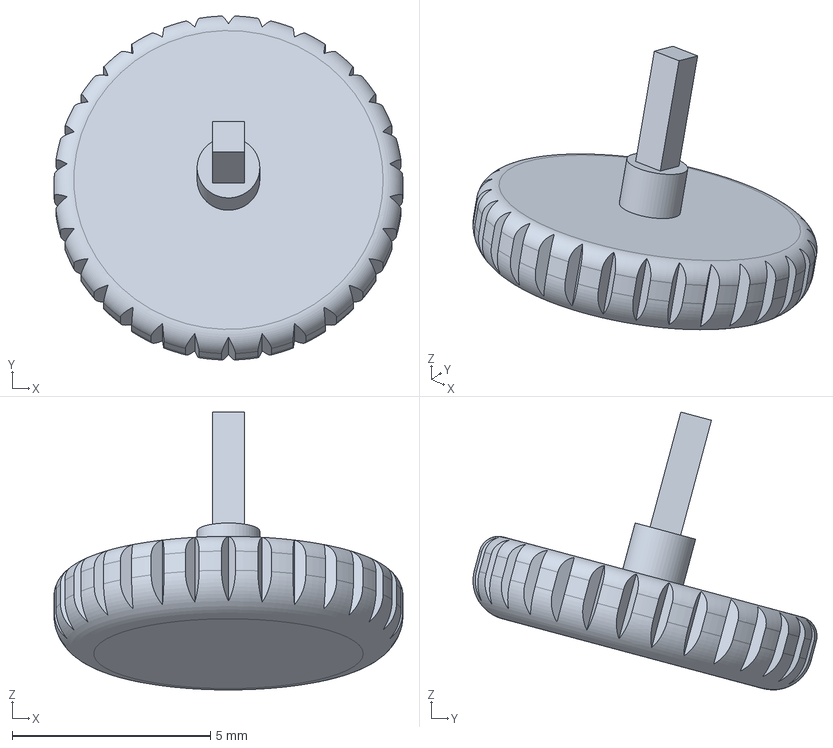
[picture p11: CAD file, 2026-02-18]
hardware/case/encoder_knob_espip-boy.FCStd
8.80 x 8.67 x 7.01 mm

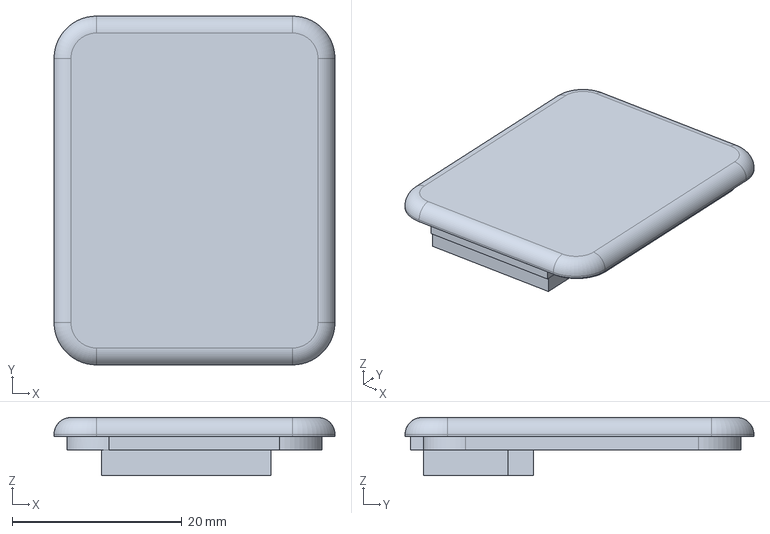
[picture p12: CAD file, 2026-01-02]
hardware/case/display_espip-boy.FCStd
33.1 x 41.1 x 6.85 mm

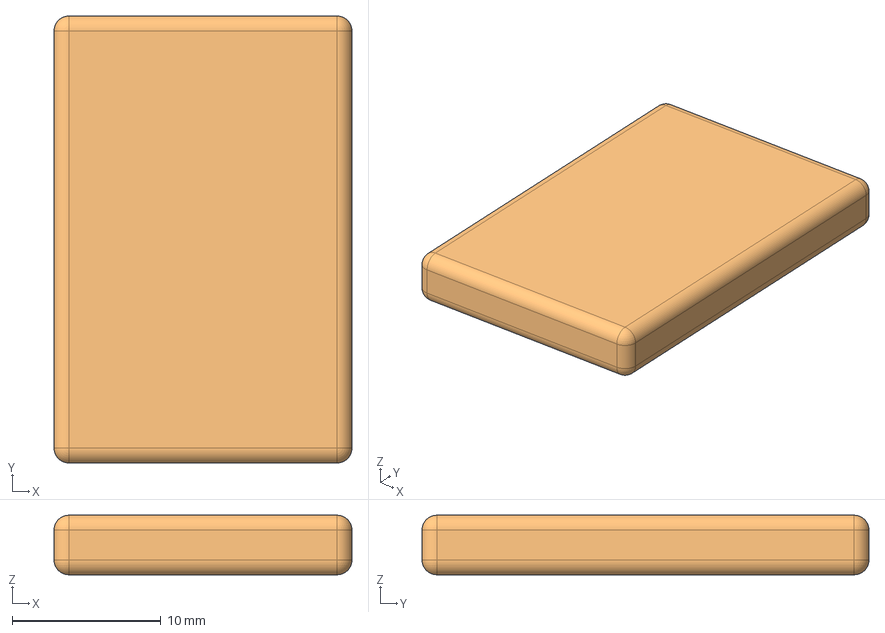
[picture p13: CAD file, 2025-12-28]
hardware/case/battery_espip-boy.FCStd
20.0 x 30.0 x 4.00 mm
battery_espip-boy_001

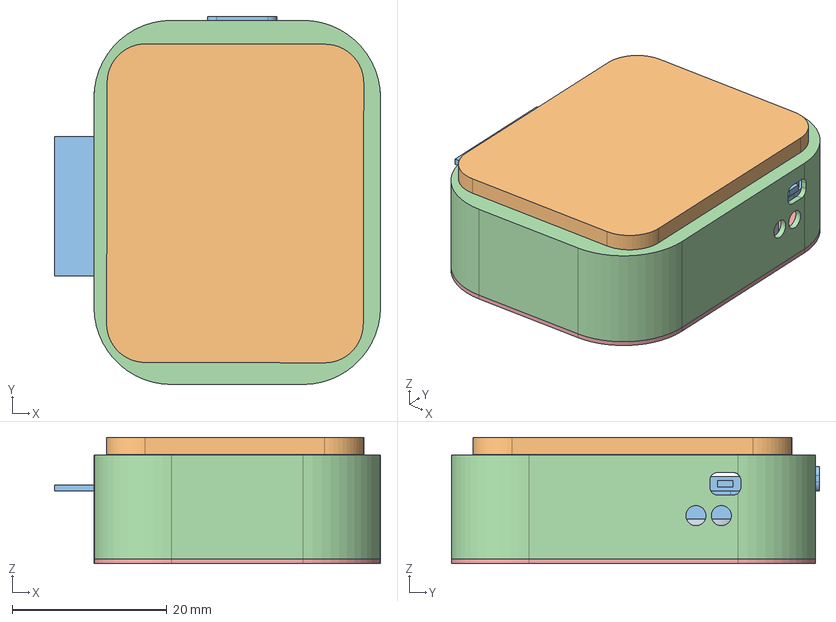
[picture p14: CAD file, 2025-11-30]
hardware/case/assem_no_encoder.FCStd
42.1 x 47.5 x 16.3 mm
battery_espip-boy_001
display_espip-boy_001
pcb_espip-boy_001
CaseTop
CaseBot

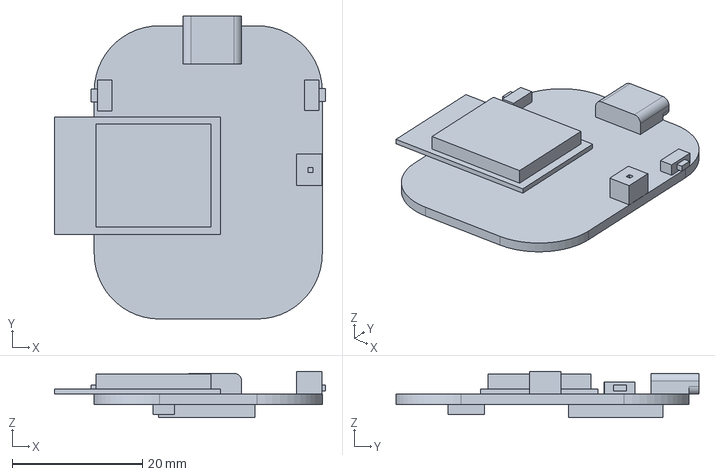
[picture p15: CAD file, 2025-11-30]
hardware/case/pcb_espip-boy.FCStd
41.6 x 46.5 x 7.10 mm

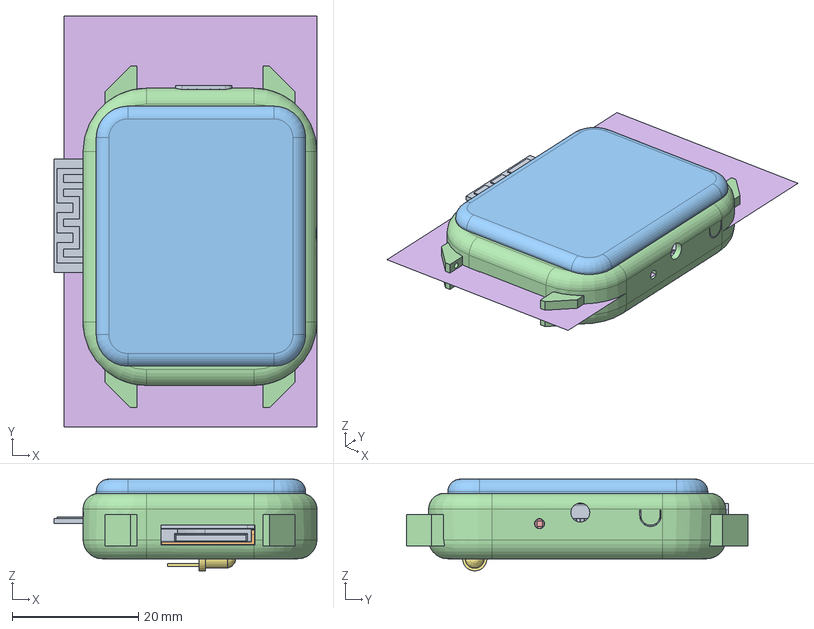
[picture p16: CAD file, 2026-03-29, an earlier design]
hardware/case/V2_case.FCStd
41.6 x 65.0 x 14.5 mm
espip_boy_rev2_less_components1_001
battery_espip-boy_001
display_espip-boy_001
case_v2
digital_crown_001
diode

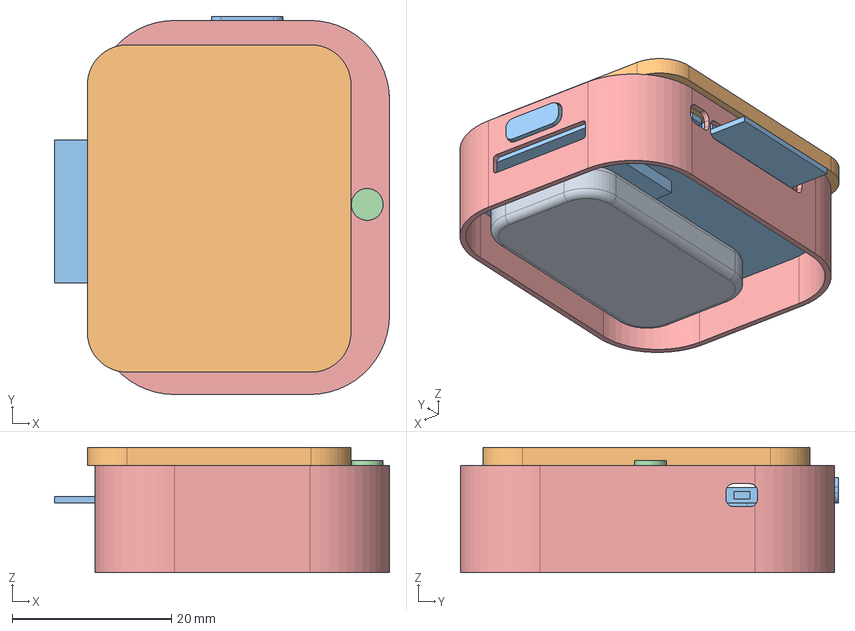
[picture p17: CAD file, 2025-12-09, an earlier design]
hardware/case/V1_case.FCStd
42.1 x 47.5 x 15.7 mm
battery_espip-boy_001
display_espip-boy_001
pcb_espip-boy_001
encoder_knob_espip-boy_001

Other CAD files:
hardware/pcb_digital_crown/BackupProjects_mgohren_personal_1_20251228.step

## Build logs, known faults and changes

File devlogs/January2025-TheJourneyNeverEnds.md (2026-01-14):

# January 14 2026 - Wednesday  2:14 AM
Just spend a while working on using EEZ Studio to configure an LVGL interface.
It's very easy to use and while a little janky to interface with the Arduino
IDE, it's not a big deal.

While I got LVGL up and running quickly as I have experience with it now, every
time I loaded my EEZ Studio files I had no errors, just a blank screen.

I did this:

1) Create project in EEZ Studio
2) Set display height and width to match project H/W
3) Set some test labels and buttons
4) Saved the project
5) Copied all EEZ files to ~/Arduino/libraries/ui/
6) Changed all "lvgl/lvgl.h" to "lvgl.h" (I also modified my .eez-project to
automatically do this.
7) Loaded a working LVGL hello world sketch
8) To #7, included "ui.h", called ui_init() in setup and ui_tick() in loop().
9) Uploaded and got a blank screen. What's wrong?

I got it! I wasn't calling lv_tick_inc() anywhere!
I copied some more timing code that uses esp32 timers from my other lvgl
testing script and it works now!

# January 13 2026 - Tuesday  7:38 PM
After waiting for my 3D printed case to come in, I assembled my watch into it's
case and wore it to work for the first time, taped together as I am still
waiting for my M1.2 aliexpress screws to hold the thing together.

I used the watch throughout the day to tell my (around 15 minutes) skewed time,
as I haven't yet programmed the watch to update it's system time from the RTC. 

I think I am happy to call this project mostly done now, as I don't see myself
redesigning the case or hardware any time soon. If the screws don't work I will
probably glue the case together. At this point, it's just software work to make
it all come together properly. And even that, I am almost done (from
a time-telling watch's functionality point of view).

I titled this month's devlog as the journey never ends because the whole point
of this watch project is to have a development platform to use the ESP32's
(mostly) entire peripheral suite in a useable tool. I say mostly because the
only thing I don't use is the ADC, which I have not heard good things about on
the ESP32 anyways.

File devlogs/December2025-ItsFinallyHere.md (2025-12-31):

# December 31 2025 - Wednesday  5:45 PM
Another tough day working with FreeCAD to get complete my case. Today
I actually sent in a .stl to get printed, but as I sent it in I noticed my
hastily designed screw terminals completely block my PCB from actually fitting
into the case!

That's what you get for throwing things together on the fly on New Year's Eve!

It's been a great 2025, and I am so proud of myself for embarking on this
journey and learning all these amazing skills. I look forward to what insane
projects I get up to next year!

# December 30 2025 - Tuesday  9:47 PM
Today I spent HOURS trying to get my case complete. Between the fillet and thickness 
tool on FreeCAD being very picky and the PCB import being very laggy it was
grueling and arduous process that I still have not completed. I think I will do
a mockup tomorrow to find the correct order to do my components.

For example, I first made a filleted pad and then made holes in it. I was
unable to make a thickness into this structure.

Then, I double back and use the Set Tip feature to add a thickness before I add
my pockets. This then resulted in my pockets not being through holes but actually holes with their bottoms sealed up. Very bizarre. 

Next I will try:
Main body pad -> thickness -> component pockets -> fillet -> watch connectors
-> split case in half -> add top/bottom half connections

I will do a quick run through these will 1 step per each (instead of doing all
the actually required holes) so that I know they work.

One thing I really need is to make the thickness inside the case, and then add
new pads to extrude the watch connectors from, without them being deleted from
the thickness operation.

# December 29 2025 - Monday 10:21 PM
PCB REV2 ASSEMBLED! It works! It's alive!

Touchscreen works great and the display cable is not folded into any sharp
corners. Only smooth bends. I'm so excited! Now I just need to finish my case
and I am all done!

# December 19 2025 - Friday 10:26 PM
PCB Rev2 on the way!

# December 17 2025 - Wednesday  9:25 PM
Today I reviewed my PCB for any flaws like via in traces or pads too close to
each other. I found nothing so far, I think one more review session and I will
be ready to order.

I also checked the rest of my so far untested circuits. This was just the rest
of my I2C devices which I already new somewhat worked due to responding to my
I2C scan. The RTC, magnetometer and light sensor all respond to my commands. So
far on the RTC makes sense though, but that's to be expected. The magnetometer
and light sensor will no doubt need some actual software for calibration.

I also found for the RTC that other brands like EPSON make a RTC with code
8010, which made me discover my YSN8010 is a drop-in clone for these devices.
I will try a library for the EPSON device soon, as the RTC is quite annoying to
use. The time components are binary coded decimal within the device, and
although it's fun to do some bit flipping, it would be even more fun to drop
a library into my project. I got the hours, seconds and minutes working, so if
I can't get a library I can roll my own.

I'm looking forward to another check over of the PCB and firing away on the
order button!

# December 13 2025 - Saturday  5:48 PM
Finished V2 of the board, back on EasyEDA. I realised using KiCAD was too much
effort for the too little amount of changes I needed to make. Tested the rest
of the components and everything is working as expected except for the motor
and the microphone. Speaker, SD card, flashlight and heartrate breakout are all
good!

Looking forward to final checks on V2 and ordering it! Also very happy the hand
assembly using hot air on the bottom worked quite well!

# December 10 2025 - Wednesday 10:00 PM
Received my new display in the mail today! Validated my touchscreen I2C circuit
works! A wonderful step. The display came with an FPC connector, I am scheming
on modifying my current board to use the new one, but flipped, to accept my new
display in a cleaner way without compromising the FPC...

Experiment failed haha. It's okay, this board will still help me to verify the
rest of my circuit designs:
I2C:
* Magnetometer
* Ambient Light + UV Sensor
* RTC
I2S:
* Speaker driver
* Microphone
External Drivers:
* Vibration Motor
* Flashlight

For now the new board design is looking promising. I've laid out some more
components, and I think I can significantly reduce the board footprint, to
allow for the battery to sit on the same plane as the PCB, further reducing
watch thickness!

# December  8 2025 - Monday 11:28 PM
Huge cleanup of git tracking.

Cleaned up entire imported EasyEDA schematic in KiCAD, starting placing
components on a brand new PCB. Racking my brain trying to figure out the best
spot for the battery and display connector. Not proving the easiest challenge.

Looking forward to getting a second board in and making a slick case. Learned
about slicing in FreeCAD today to make a much better clamshell design that the
PCB can sit in, not the V1 design that I had to shove it in due to the deep
cutouts for the antenna and USB port. 

KiCAD and FreeCAD are awesome software. I look forward to contributing soon!

# December  7 2025 - Sunday  7:38 PM
Unfortunately my luck has run out with V1.0. After designing and printing the
case, and placing my components inside, my watch worked at least to the point
of displaying correctly. However, due to the mangled FPC connector of the
display, the I2C bus was broken. The only way to fix it? To move the display
around, jiggling and bending and hoping and praying. Not effective. My luck
finally ran out when I went to remove the friction fit display (which fit
wonderfully), and accidentally pried the backlight off of the display enough to
cause corruption in the display, like unwanted lines of the wrong colour
throughout the display. It's busted. 

It's here I officially can say V1.0 has been tested to the point of critical
failure, and the list of improvements is beginning to emerge for
V2.0:
* Place the display connector in such a way as to remove ALL force on the
  display connector
* Use right angle, SMD LEDs instead of a discrete solution
* Make all SMT pads for external speakers and vibration motors through hole for
  better stability

So far that's mostly it, I am pleasantly surprised with how well everything has
gone with the V1.0 PCB, and I am looking forward to building the next revision.

With that being said, I am learning and moving to KiCAD as my EDA tool. The
main reason for this is that .STEP file export is free, compared to the $20
monthly subscription fee for this feature on EasyEDA. The .STEP export will
allow me to really fine tune the case design, which now that the hardware has
been validated, is the next challenge to really bring this project home.

So far the only bump in the road with regards to KiCAD is that my easyeda2kicad
3D models are sometimes offset from the footprint. Otherwise the symbols and
footprints are perfect!

# December  3 2025 - Wednesday 12:23 AM
Working on the SW to get it to a decent, useable state. Currently trying to
drain the battery to let the fuel gauge learn the battery State of charge. 

I am doing this by just printing the battery voltage to the display, and never
sleeping it. I've disabled the sleeping as I've added it right after the screen
off calls. Soon, I will have a watch that turns on when the user moves the
right amount (the watch focus gesture is pretty bogus so far), displays the
time and then sleeps after a 10 seconds of inactivity. 

Then I will add NTP time sync and time sync with the RTC after perhaps 24 hours
for the WiFi sync and 5 wakeups with the RTC, to be tuned of course, storing
the boot count in the RTC memory!

# December  1 2025 - Monday 12:33 AM
This is a pretty surreal feeling now, as I just finished up the auto wake
feature for the display on my smartwatch. I am actually wearing it, after
I installed a battery disconnect switch for some peace of mind, and installed
the assembly into a crappy plastic chopped up case and taped it in with an
actual watch strap to hold it on my wrist.

I am so happy it works! So far the auto wake is simply polling the
accelerometer, but I hope to use the wrist wake feature so that I can avoid
polling and safe battery by sleeping the CPU when it is in rest. However, the
default really sucks. It's borderline useless. The next thing I want to develop
is a proper, working wrist gesture interrupt with the BMI270, and then
implement low power sleep, and then after those 2 features, start adding low
power polling to my other peripherals like the magnetometer. All the while,
I will be making current draw measurements and battery life measurements using
my multimeter.

Looking forward to installing the real time clock and actually having
a functioning, decently featured smart watch!

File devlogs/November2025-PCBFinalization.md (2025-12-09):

# November 26 2025 - Wednesday 12:13 AM
No words. It's alive. 

# November  7 2025 - Friday 4:03 PM
Parts and PCB ordered.

# November  5 2025 - Wednesday  9:58 PM
The last few days have been a lot of analysis paralysis. Being so close to
finished, I am more nit-picky than ever. Today I did my USB differential pair
and I spent hours wondering if I should include vias or route under the USB
connector or this or that or whatever. I decided I will do my best,
understanding that I won't ever have perfect signal performance and that's
okay. I also have 0 experience, so I have no instincts to base my intuition on,
it's just a mass of information that is overwhelming, and a lot of "that
shouldn't apply to you unless you're doing USB High Speed". I've decided my
differential pair and some vias should be fine.

I went over my BOM and started cleaning that up too. Added a footprint for the
MAX30102 heart rate and blood oxygen sensor, and then removed it from the BOM
because it costs 12$ on LCSC for whatever reason. Now I have an I2C breakout
and an actual footprint for it. Nice.

I am so close to ordering! Let's Go!

# November  1 2025 - Saturday  4:25 PM
Today I looked over every connection in my schematic, placing links to the
relevant reference schematics I've collected over the past few months.

Aside from some small changes including adding some 0 Ohm bypass resistors for
my battery into my battery monitor IC, and some more for the config of my
speaker driver, I found a big problem.

My display connector is backwards! If I leave it how it is, I would have to
wire my display in upside down! I won't be fixing this today, but hopefully it
is not as disastrous as I imagine it will be. I'm so glad I caught this!

Aside from fixing the display connector, my only other plans are to review the
PCB implementation of my now fully reviewed schematic, and then add copper
fills and thick ground traces for some more safety. Other than that, this
design is looking dangerously close to order time. >:).

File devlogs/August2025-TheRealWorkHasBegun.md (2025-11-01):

# August 28 2025 - Thursday 11:59 PM
USB reading and implementing the schematic. Found some nice resources like the
[ESP
devboards](https://docs.espressif.com/projects/esp-dev-kits/en/latest/esp32s3/esp32-s3-usb-bridge/user_guide.html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)
and some engineering blogs @ [matthew
lai](https://github.com/matthewlai/hex0ad). 

Tested out my vibration motor, super easy, just analog write the pin. The motor
board comes with a driver transistor which is great because it draws up to 90 mA
and ESP32 pin is max 40 mA. 

Got my LiPo charging working with a LiPo I had laying around, but the onboard
esp32 regulator needs like a 1.5 V overhead, when I throw my 4.1 V lipo on, the
regulator only gets 3.0 ~ 3.1 V output. It would probably work with that but I
won't bother. I'll have my new regulators soon, with a much lower ceiling. 

Working on the microphone now, but will probably give it a rest, I soldered the
pins on upside down so now I can't see the silkscreen haha. 

Goodnight!

# August 27 2025 - Wednesday 06:12 PM
A light day today, just some reading and part selection for UFL antennas and
learning that MH1 (NOT MH4) is compatible with UFL. I like the ESP32-WROOM-32UE
with the UFL antenna, it will make my case smaller, because I won't need the PCB
antenna sticking out over the side of the board. I can instead poke it through
the case and then wrap it around and adhere it to the case! This should result
in better signal as the UFL antenna's have better signal. The only problem is
they expect 5mm of keepout area behind the case (on the inside) which is kinda
goofy. I'll have to see if that is necessary or I can just avoid it. If I can't,
I may just use the 5mm of PCB antenna then on the inside.

I also did some reading and found some resources about USBC. I would like to
have it on my board but there are obviously some more complicated design
considerations, but I believe it is only adding a pull-down resistor to a CC
line (what is a CC line?) and connecting the pairs of D+/D- lines together.

# August 27 2025 - Wednesday 12:48 AM
A nice night working on A2DP connectivity with the SD card. Works OK-ish. I can
literally block the signal with my hand, and "wearing" (holding the breadboard
		in my hand and fake jogging) the watch on the left side of my body is
almost no connection while the right side is fine. I guess that's where the
receiver is on my headphones. I gotta say, for just a bare ESP32 chip with a PCB
antenna, it's "good enough". I am interested in investigating external antennas?
Perhaps they will have better performance for my use case. 

Also did some research on PMICs. I found ( ChatGPT told me) the Analog Devices
ADP5360. A great charging chip with a fuel guage, battery protection and power
supply through buck and buck-boost convertors. I also found the MAX17XXX
something that has a (much?) better fuel guage as a seperate chip with time to
full and time to empty estimates. I would need to do my own battery protection
and charging and buck though, so IDK if this is worth it. I will do some more
research.

So much research!

# August 25 2025 - Monday 11:25 PM
Back in the saddle. I had a great weekend fishing trip with the family and it
was wonderfully refreshing. The lack of clarity I felt earlier is gone, the
mission is now to diffuse the cloud and start moving in measured steps.

I am now choosing components. I have finally settled on mostly every feature I
want in my watch now and the prototyping is finished. It is now time to dial in
each component so that I may start working on my schematic. 

I am making a list of part numbers, features they implement, current and voltage
figures for rough power estimates etc. I am so excited once again!

# August 21 2025 - Thursday 11:25 PM
Today I went to work on my watch and the lack of clarity set in.

Having mostly finished the prototype, it is time to move on to the next step of
selecting a vendor, parts and designing the PCB. I dislike LCSC and will most
likely use Digikey. 

However, I have no experience designing PCBs so this part of the process is
still scary to me. Following Robert Feranac's tutorial was great but it just
demystified the amount of work I have to do haha. 

I made my state even worse by looking for inspiration on other watches and felt
discouraged by the Reddit comments telling unprepared and overly optimistic
posters that unless they wanted their watch to look like a Pip-Boy they need to
rethink their design. These are the comments that inspired the name of this
watch, but now they are discouraging instead of inspiring me. 

My main issue now is my GNSS module. I refuse to design an onboard antenna or
even interface with a U.FL connector. This severely limits my design to
expensive modules, with the cheaper ones being massively large. I have to
accept these options or see if I can use an existing L1 band antenna like
I found for the WiFi antenna.

All that being said, the road ahead is new territory for me. It is unknown and
will require lots of hard work and study to conquer the concepts and make
a working product. I am confident though. I will take my time, take this
weekend off for a nice fishing trip, and come back with clarity of mind to
continue the project. 

It is interesting to finally be 'sick' of the project haha, it is
all-consuming, and the novelty of that has worn off. 

I look forward to returning to the next Act of this project with renewed
confidence :).

# August 21 2025 - Thursday 12:13 AM
I feel like a mad scientist. Staying up late every night to work on my wonderful
creation. It is paying off though. I have never worked so hard on something, and
have never received such satisfaction. It is a beautiful thing.

Today was spent adding a buzzer and a menu to be controlled by my EC11 rotary
encoder. Very wonderful. I now have a menu and some 'apps' haha. A true device.
I also spent around $60 on more components to play around with: SMD LEDs for
flaghlights and colour, microphones, vibration motors and I almost bought a
pieze beeper but remembered I have one. It works well!

Now that the prototyping is nearing an end, with all of the complicated pieces
working properly together, I am interested in finalizing the design so that it
can become a nice schematic and PCB. This means the next couple of weeks will be
a lot of researching components and deciding once and for all (at least for this
revision) the components I will use. 

I have started my document and I am comparing and contrasting different GNSS
modules. I believe I have found my special one. The Quectel LG86. A great
compromise between ease of use and integrated antenna. I am looking at this one
with heart eyes because so many modules on the market do not come with an
antenna, or have different logic levels, but this one actually fits the
"perfect" description I made at the top of the table haha. I will keep looking,
and if nothing beats it, I will use it in my final design!

Goodnight!

# August 19 2025 - Tuesday 12:42 AM
I am finally breadboarding my watch as one unit. SPI bus with SD card and TFT
display, I2C bus with MPU 6050, light sensor and heart rate monitor. Soon I will
reinstall my EC11 and make a menu on the TFT display for the user to select an
app: clock, heart rate display, compass ( if I use the magnetometer chip -
currently I have the MPU6050 installed. I want a 9 axis IMU haha ). Very
exciting!

# August 16 2025 - Saturday 09:39 PM
The EC11 schematic is complete! I have wired, tested, watch an episode of
Shogun, and drew the implementation of the EC11. Very simple, and I added +3V3
pullups to the input pins 34 and 35 as they do not have built-in pullups. 

This is an efficient use of pins because these are input only, and I won't/can't
use these for SPI and I2C peripherals, saving GPIO resources.

Currently I am researching the part of the project I understand the least about:
LiPo/Li-Ion battery circuits. I understand I will have a Micro USB port with 5V
going into a TP4056 charging IC with indicator LEDS. I will have this connected
somehow? to a DW01 protection IC to stop over/undercurrent of my lipo. 

The final thing I want, which is detailed nicely in this video, [Load Sharing
with
LiPos](https://www.youtube.com/watch?v=wy516po6uVU&ab_channel=MicroTypeEngineering)is
load sharing. Load sharing is a concern when you are charging an integral
battery because the charging circuit senses current to tell when the battery is
finished charging. If you have your load connected, it will draw current and
tell the charging IC the battery is not fully charged yet, resulting in the
battery being constantly trickle charged when plugged in to USB. 

The simplest solution presented in the video, which I would like to implement,
is adding a transistor controlled by VBUS which disconnects the load when
VBUS is high. 

After today and seeing how comfortable I am with designing after physically
testing, poking and prodding the components, I will order some of these
battery ICs and LiPos in order to test and learn more about them.

# August 17 2025 - Sunday 08:11 PM
Got the SD Card working! Needed to format to FAT32, as it came factory formatted as exFAT. I haven't tested the capacity yet but hopefully the 64G works, I don't see a reason why not!

Test Results:
==== ESP32 SD Thorough Test ====
20:09:36.444 -> [BUS] Using VSPI
20:09:36.444 -> [PINS] SCK=18  MISO=19  MOSI=23  CS=5
20:09:36.444 -> [MOUNT] Trying SD.begin(CS=5, freq=20000000 Hz)... OK
20:09:36.590 -> [MOUNT] Mounted successfully at 20000000 Hz
20:09:36.590 -> [INFO ] Card Type: SDHC/SDXC (>=4GB) (code=3)
20:09:36.590 -> [INFO ] Card Size: 58.30 GB (59700 MB)  == 62599987200 bytes
20:09:36.590 -> [DIR] Creating dir: /test_sd ... OK
20:09:36.638 -> [WRITE] /test_sd/hello.txt
20:09:36.638 -> [WRITE] wrote 34 bytes
20:09:36.638 -> [READ ] /test_sd/hello.txt
20:09:36.638 -> [READ ] Content:
20:09:36.686 -> -------------------------
20:09:36.686 -> Hello from ESP32 SD test!
20:09:36.686 -> Line 2.
20:09:36.686 -> -------------------------
20:09:36.686 -> [APPEND] /test_sd/hello.txt
20:09:36.686 -> [APPEND] appended 15 bytes
20:09:36.686 -> [LIST ] / (root, depth=2)
20:09:36.686 -> [LIST ] Dir: /
20:09:36.686 ->        208  autorun.inf
20:09:36.686 ->   <DIR> System Volume Information
20:09:36.686 -> [LIST ] Dir: System Volume Information
20:09:36.686 -> [LIST ] Failed to open directory
20:09:36.686 ->      34494  autorun.ico
20:09:36.686 ->      12384  Screenshot 2025-03-08 143958.png
20:09:36.686 ->   <DIR> test_sd
20:09:36.686 -> [LIST ] Dir: test_sd
20:09:36.686 -> [LIST ] Failed to open directory
20:09:36.686 -> [RENAME] /test_sd/hello.txt -> /test_sd/renamed.txt : OK
20:09:36.735 -> [REMOVE] /test_sd/renamed.txt : OK
20:09:36.735 -> [BENCH ] Starting binary R/W benchmark with verification...
20:09:36.735 -> [BENCH ] Writing 8 MiB to /bench.bin in 4096-byte chunks...
20:09:41.996 -> [BENCH ] WRITE: 8.00 MiB in 5.26 s  =>  1.52 MiB/s
20:09:41.996 -> [BENCH ] Reading 8 MiB back and verifying pattern...
20:09:47.554 -> [BENCH ] READ : 8.00 MiB in 5.56 s  =>  1.44 MiB/s (verified OK)
20:09:47.554 -> [BENCH ] bench file removed.
20:09:47.554 -> [BENCH ] Completed successfully.
20:09:47.554 -> 
20:09:47.554 -> ==== Done. You can reset and re-run if needed. ====

# August 16 2025 - Saturday 03:10 PM
I was stuck on my EC11 schematic today, surprised at the lack of information. I
decided, having purchased one already, the best thing would be to interface with
it and see how it works.

OMG the EC11 is a way different beast than I thought. OMG even the switch is
more complicated than I thought. Today I learn about quadrature encoding: the
way the EC11 rotary encoder encodes position into a signal. 

The digital pins into a rotary encoder and pulled high, and depending on the
rotation of the knob, the output signal to GND will be in a different phase. Pin
A will be leading if it rotated towards A and Pin B will lead in phase if the
knob rotated towards B. 

What the hell hahah, I did not expect this. 

Even the switch on the EC11 was more complicated than I thought, requiring me to
enable the digital output to GND through the switch as an INPUT_PULLUP, and then
monitoring the pin for when it is being pulled to ground. 

This will be a great experience item to use as an RTOS task, to monitor the
EC11, perhaps with interrupts, so that I have a responsive display while
multitasking.

Now that I understand the EC11, I will make my schematic for it!

* [ESP_Knob Lib](https://github.com/esp-arduino-libs/ESP32_Knob)
* [Button Tutorial](https://docs.arduino.cc/tutorials/generic/digital-input-pullup/)
* [Incremental Encoders and Quadrature Encoding Wikipedia Page](https://en.wikipedia.org/wiki/Incremental_encoder)

# August 16 2025 - Saturday  1:12 PM
    Wow, it's been a while. I have been super busy since I came back from
Japan.  In order to keep the dream alive, I planned to get to work on my
schematic and PCB this weekend and boy did I.

Yesterday, I spent about 10 hours doing 2.5 hours of Robert Feranac's tutorial
on designing an ESP32 development board schematic and doing PCB place and
route.  What an absolute monster of a tutorialRobert Feranac's EasyEDA ESP32 Dev Board tutorial.
I can't remember the last time I focused on a project for that long in one day
haha.

But the tutorial paid off, and today I am finally working on the ESPip-Boy's
schematic! I have copied and pasted the ESP32 board from the tutorial and
I have added labels for the components I am missing. Mostly sensors, battery
charging/protection and the rotary encoder switch and I am currently working
on.  [EC11 Schematic](https://electronics.stackexchange.com/questions/512042/does-ec11-incremental-encoder-need-hardware-debouncing-and-vcc-for-encoder)

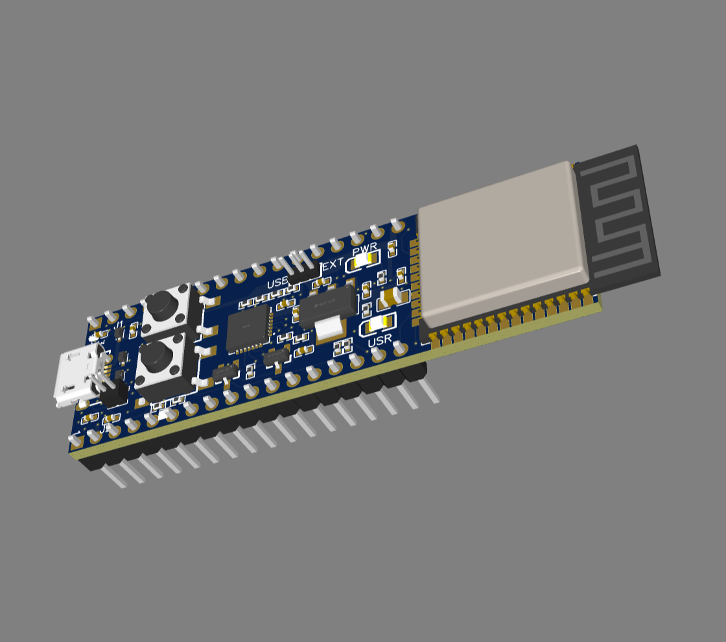
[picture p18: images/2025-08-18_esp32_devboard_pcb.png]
ESP32 Tutorial Dev Board Complete!


It is so exciting to have finally reached this point in the project!

# August 1 2025 - Saturday 4:18 PM

  It is now August and I can say the real work has begun. The spectactular
dreaming phase is over and it is time to put my nose to the grindstone. To stop
being afraid of the unknown work ahead and to just do it! Today I started with
a simple 5 minutes of placing most of the labels for the USB Serial convertor.
Unfortunately that's all I could handle before becoming quite tired.

I will blame it on my jet lag from my 2 week Japan trip haha.

But that's the goal. Just chipping away at it every day, little by little.

I can already see the improvement in my PCB design skills, taking what I've
learned from the first 25 mins of Robert Feranac's ESP32 Dev Board video and
doing it on my own with no handholding, just referencing and making sure I am
on the right track.

This is very exciting for something I've never done before, watching my own
skills develop before my eyes! Here's to patience and curiosity as I walk this
unknown path!

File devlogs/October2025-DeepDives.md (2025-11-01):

# October 29 2025 - Wednesday  5:50 PM
It's done already! Today I finished V1.0 of the ESPip-Boy PCB. I can't believe
I'm writing this! I will add the schematic, PCB files and screenshots of the
model when I am done checking every thing over 10 times, as well as making any
final cleanup. That was surprisingly fast!

I can't wait to do my last check ups and cleanups, as well as have some
friends have a look at it, and then send it off to the PCBA house! 

# October 23 2025 - Thursday  1:38 PM
Today is the official start of PCB day. A couple quick hardware validations on
the bench to start off though:

1) Do I need a pullup resistor on an input only pin for I2S? No, testing SD
Input on D35 with my i2s_to_wave sketch. 
2) Does an IMU interrupt work for waking up the ESP32 from deep sleep on pin
33? Yes, it does and it works great!

Time to start on the PCB, for realz this time!

# October 22 2025 - Wednesday  8:52 AM
Got the LED fully off! I rebuilt the circuit in the same way, but with
a different MOSFET from my pack of 2 that I bought. The source leg of the first
one broke off, so I am wondering if there was a fault there. I am also
wondering if because the circuit was farther away that my ~6cm cable had enough
capacitance to keep the gate on? I am not sure, but I am sure that it is
working now! It was super weird, without connecting the cable to the ESP32,
just holding it in my hand, the light would turn on shortly! Maybe I was
discharging static electricity into the gate?

# October 21 2025 - Tuesday  9:16 AM
Got the flashlight circuit working today! It is the last thing on my schematic
that I haven't breadboarded! It's basically a copied and pasted driver from the
LCD backlight circuit. I have a second transistor so I will probably try
running that as well.

The only problem I have is that the LED does not turn off fully at 0% duty
cycle and I am not sure why. I tried digital writing low and detaching the PWM
circuit but no luck. Maybe it is something with my circuit then.

# October 17 2025 - Friday  8:59 AM
Finished the last module! My flashlight driver! 

I need to learn more about MOSFETs to understand the way they work and more
importantly how they switch larger currents. BJTs make sense to me but I've
forgotten everything I learned in school about MOSFETs. 

Schematic just needs fine tuning now, no more additions!

# October 10 2025 - Monday 5:02 PM
A Thanksgiving simulation for the Flashlight driver:

For a ballpark 100mA current running through an LED, I need a BJT switch to control
the current.

Using the NPN on falstad.com with an hFE of 30 (like the 2N3903).
This means I need an Ib of Ic / hFE => 100mA / 30 = 3.33 mA. Perfectly doable
on my ESP32 GPIO pin. In order to get this from the 3.3V pin output, I need
a current limiting resistor of Rb = (Vin - VRb) / Ib = (3.3V - 1V) / 10mA = 230
ohm.

Simulated on falstad and it works well!

I have also added a 10 ohm current limiting resistor, which dumps around 150mW
of heat from 100mA. A nice 0805 or 1206 size can dissipate around 200-400W
[Vishay SMD Resistor Datasheet](https://www.vishay.com/docs/28705/mcx0x0xpro.pdf), so it won't explode,
but it is not the most efficient, especially in my battery operated device.
I am OK with this though, as I am running this in my LCD Backlight LED driver as well.
A more costly alternative is a constant current driver like a regulator, but
I want to save some money on my PCBA by reducing component count where I can.

# October  8 2025 - Wednesday  9:01 PM
Deleted the GPS, wired up the TI fuel guage.

Looks like I was confused, it uses a high side sense resistor. I (believe I)
need to connect the BAT+ terminal to the BAT connection, and then connect the
SRX (sense resistor pin) to the power supply input. This makes sense to me from
my INA219 current sensor usage: it's just a series resistor the chip uses to
make measurements. I must pass the current in and out of the battery through
this resistor to make any meaningful readings. However, without the board on my
bench, I do not trust my datasheet guesses. I added a 0R resistor on the SRX
pin so that I may disconnect my battery from it, and wire it directly to the
input of the LDO as originally planned. 

I ran the design rules checker and cleaned up a few nets. It's almost too good
to be true haha. It feels wrong to say but the schematic is done. I say wrong
because I am not one to finish things and call it done, I like a neurotic and
obsessive amount of checking things over, which I will do in the coming weeks.
During the checking, I will also be placing and routing the components on the
PCB, to start getting reps in there, and seeing what fits where and what
doesn't work.

My brain is fried, and I am done for the day. Hoorah!

# October  8 2025 - Wednesday 12:13 AM
Today I finished the TI Fuel Gauge and the LDO Regulator on the schematic.

The TI fuel gauge is a little confusing with respects to the SRX pin. The
datasheet says to connect this to VSYS, the system power rail. But then says it cannot exceed VBAT + 0.3. Then on online forums they say connect it to the *input* of the LDO, not the output, which I would think is the system power rail. So I am connecting it to the battery pin itself, not the system power rail. I hope it works!

I am really enjoying working on the schematic seriously now, knowing that the
prototype is almost finished. The only thing left to do on the prototype is
verify the interrupt functionality of the MPU6050. Other than that, its truly
schematic time. 

I am on the fence about including the GPS, and will most likely remove it to
save space on this design. I anticipate not using it nearly enough to justify
it's cost and inclusion, but I will decide later as I encounter it on the
schematic. I just think it's not necessary!

# October  3 2025 - Friday 10:32 PM
Schematic Work! 

The prototype has come along so nicely now that the microphone and speaker have
been proved out, sharing the serial and bit clock lines. This saves me
a couple of pins, and I am using all four input only GPIOs on the ESP32 for my
rotary encoder and Mic in. 

All that is left now to prove out on the prototype is the necessity of a GPS
and the interrupt pin for my BMI270 accelerometer (this will be tested with my
Aliexpress fake MPU6050 haha). 

The necessity of the GPS will be decided after I render a JPEG of a map on my
display. I anticipate it being too low res for any worthwhile usage, which then
makes me question the need of a GPS. My use case for it is rendering my real
position on top of a JPEG of a map, so that I can trace paths I run or hike and
provide a live position/movement of map. If the map render does not look good,
I don't need the GPS. It would be nice to have for a spedometer, but not worth
the development time at that point.

The accelerometer will be very easy to do, I just need to wire it up and attach
the interrupts. Then, do a little sleep test and see if it can wake it up
(which I am confident it can). 

As the hardware prototype finishes up, and I am more interested in removing
parts as much as adding them, I want to prepare for more PCB work. I am closing
in on finishing the schematic along with the prototype, and then all that is
left is my PCB design and order! However, I am really not comfortable when it
comes to the PCB design aspect. It's a big project and I have very little
experience. 

I plan to take some time to do some tutorials, as well as make simple designs
like I2C breakout boards for sensors and battery modules. That way, when it
comes to the interaction of all the different buses and components on the full
project, I will have the experience of doing the smaller components first!

# October  2 2025 - Thursday 11:44 PM
I spent the night tonight writing a WAV File decoder. I read the [1991
specification](https://www.aelius.com/njh/wavemetatools/doc/riffmci.pdf) by IBM and Microsoft, and got confused so I consulted the wikipedia page which helped a lot in describing the actual byte counts of the fields in the header (I got stuck on the omitted chunkSizes in the weird description format used in the official spec.). 

I was able to successfully decode ALL BUT the data size of my recording from my
ESPip-Boy microphone. I am still not sure why the data size is returned as
a zero. My code is dead simple, but alas, the bug is invisible to me.

I am super proud of myself for allowing my curiosity to take me to the real
documents that outline this technology. I am very happy to not need to rely on
generative AI to solve these problems for me, when the information to solve the
problem yourself is so readily available. 

I can't describe the joy of writing a simple C program to load a WAV file and
print the first four bytes and seeing the 'RIFF' pop up in the console. It
feels like my first "Hello World" all over again!

# October  1 2025 - Wednesday  9:37 PM
It's the first of October! Today is the day that I've learned an important part
of embedded software engineering (and really all software engineering). Domain
knowledge vs. programming knowledge.

Over the last 5 years I've really become an avid programmer from basically
not knowing anything about it (I wrote my first program in my last year of
highschool before leaving to uni for electrical engineering). In that time
I have gained a solid grasp of C programming and low level software - bit
manipulation, pointers and memory addressing etc. However, I've only scratched
the surface of other digital domains: audio, video, image processing and
communication protocols. This is why I love this project so much, it exposes me
to ALL of it!

As I have the programming experience, the thing that is missing is the domain
experience. I have no problem reading or writing data to a circular queue of my own design. But sending PCM audio to an I2S device? Both concepts may be fundamentally identical, but the audio problem presents so much new language, so many new concepts, and so many ways to organize the simple flow of data from A to B that it becomes an entirely different situation.

My wake up call was yesterday when I finally recorded audio from my MEMS
Microphone to a WAV File on an SD card. After searching the web and trying so
many code snippets, cutting and pasting and modifying endlessly, I only found
success when asking ChatGPT to do it for me. I am not proud. It made me realize
that while I have a high level understanding of the digital and analog domains
my smart watch operates in, what software and hardware is required to make it
work, I have NO IDEA how it actually operates under the hood. Enter the deep
dive. 

From now on, I would like to deep dive into my components and modules, and
actually learn enough to make them work "from scratch" (within reason haha).
I want to write my own SPI drivers. I2C drivers. Create my own sine waves and
write them out to I2S devices. How do I generate a sine wave to become an audio
signal? How does PCM audio work? What is PCM audio?

Now that I have proved out that all my ideas work over the last couple of
months with boilerplate code, it is time to actually get my hands dirty
(dirtier) and learn the concepts behind all of the wonderful audio, imaging and
communication that makes my prototype ESPip-Boy function so well.

Here's to deeper understanding, here's to endless curiosity and here's to the
wonderful fascination that is embedded software engineering!

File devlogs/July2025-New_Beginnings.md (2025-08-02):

# July 16 2025 - Wednesday 7:16 PM
RAHH! Started the PCB Design!

Working on [Robert Feranac's EasyEDA ESP32 Dev Board
tutorial](https://www.bing.com/videos/riverview/relatedvideo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).
It's a daunting 3 hour video, but it is a necessary watch for me. I have never
done a PCB design **EVER**, and this will be a great experience for me. It
seems simple enough to take smaller projects like a development board and
tacking on my modifications for my smart watch: sensors, LED flashlights,
displays!

So far I got through 25 minutes of laying out components and starting to label
the ESP32 module. I have learned a lot about choosing the components
themselves, and started understanding enough to ask how/why we choose
components. Why certain sizes? What limitations do we have as PCB designers? 

I do like EasyEDA as it is connected to JLCPCB's inventory so you can see price
and inventory right when you choose components, and with just one click you can
see how one seemingly identical capacitor can be 10 times as expensive as it's
counterpart. 

This PCB design is the scariest, most daunting part of this project. So much to
learn, so much time to wait and money to be spent on developing, making
mistakes, fixing them and trying again...

Despite all that, I am so happy to have finally started the process!

# July 16 2025 - Wednesday 5:08 PM
Two hours later... got the TFT Display working!

I had a lot of difficulty with this, simply trying different wiring
configurations over and over and different code. I tried the Adafruit library
and the TFT_eSPI library.

Turns out you need to understand the libraries you work with! The TFT_eSPI
library requires the user to fill out User_Setup.h to provide the pins they
used for the display. Once I filled this out, I can now use any example in the
library and it works great!

Also, there is a helpful diagnostic tool that reads the user setup out to you
while writing the whole display red. Here is the pin config that worked for me.
I referred to the previously linked ESP32 datasheet to use proper SPI pins for
CLK and MOSI, but the file already had suitable pins anyways.

[code]
TFT_eSPI ver = 2.5.43
Processor    = ESP32
Frequency    = 240MHz
Transactions = Yes
Interface    = SPI
Display driver = 7789
Display width  = 240
Display height = 280

R0 y offset = 20
MOSI    = GPIO 23 // marked SDA on board
MISO    = GPIO 19 // my board does not have one of these
SCK     = GPIO 18 // marked SCL on board
TFT_CS   = GPIO 15 
TFT_DC   = GPIO 2
                  // maybe not necessary in this library but I have 
                  // RES pin -> pin D4

Font GLCD   loaded
Font 2      loaded
Font 4      loaded
Font 6      loaded
Font 7      loaded
Font 8      loaded
Smooth font enabled

Display SPI frequency = 27.00
[/code]

The display runs great! Animations and frame rate are very
smooth, I am very happy with today's work. 

I forgot to mention that I solved July 14th's problem of not having a big
enough breadboard that by cutting mine in half... with an exacto knife haha.
Took me 20 mins but well worth it, I can now properly use all of the pins with
the breadboard instead of having them unavailable due to the width of the
board.

### Today's Lessons
* Do not use the Dupont connectors I have lying around (I did not crimp them
  properly and they are unreliable - remove them and just use the solid core
wire)
* RTFM (always)
* Display runs fine on 3.3V
* BLK pin can be tied to 3.3V for constant max backlight brightness

# July 14 2025 - Monday 11:35 PM

Attempted to get the TFT display working, but no luck. Only a small lighting of
the display backlight upon grazing a random pin with a jumper cable.

My issue I learned is my breadboard is too small for my curent esp32 dev module,
which is wide enough that only 1 strip of holes is available on one side.
Documentation is also a little scarce, but there are enough YouTube videos
that I am confident I can get it to work. 

I will acquire a larger breadboard so that I can be confident in my
connections instead of holding 3 jumpers against 3 different pins!!!

[TFT Hardware
Setup](https://www.youtube.com/watch?v=3rDjwMwcFRs&ab_channel=DoIt.20)

# July 13 2025 - Friday 04:21 PM
GPS testing! [BE-180 GNSS Module](https://www.beitian.com/en/sys-pd/522.html)
* GPS TX -> ESP32 RX haha, not TX to TX!
* Don't use SoftwareSerial, use HardwareSerial as ESP32 has multiple
* GPS needs to fix, even if PPS/TX are blinking, still may not have a fix: 2-5
  mins outside
Hardware was super easy to setup, the module includes some cables that all
I needed to do was strip and slip into the breadboard. I've never worked with
serial communication though, so I made the mistake of connecting TX to TX haha.

Software was simple as well, I just changed the pins to 16 as this is the
UART2RX (Second Hardware Serial module on the ESP32). Adapted the 
[Arduino Get Started GPS
code](https://arduinogetstarted.com/tutorials/arduino-gps).
I was getting garbage, so ChatGPT helped me with changed the baud rate to see
which one would be correct, and it turns out 384800 works for me. I thought it
would be selectable through the code but perhaps the machine is hardcoded for
a speed until otherwise. 
* Installed TinyGPSPlus by Mikal Hart. 

After about an hour and a half of tinkering and vibe coding, I was able to
translate the coords given from the BE-180 to my live location at 
[GPS Coords and Map](https://www.gps-coordinates.net/). 
This concludes the hardware validation for my GPS App. 
The next step will be downloading map data and then rendering it with
a position marker. But let's not get ahead of ourselves 😈.

Another one bites the DUST!!!

# July 11 2025 - Friday 06:40 PM

Got the LSM303 (GY-511 package) working!  

Compared to my real reference compass, it seems off but I will call this a
calibration/heading issue.  The setup required calibrating the device by moving
it in all 3 axes while running the Calibration example found at [LSM303
Library](https://github.com/pololu/lsm303-arduino/blob/master/examples/Heading/Heading.ino)

Then I ran the Heading example and saw that the reading was not very
accurate, but I am okay with that for now. First sensor interfaced
successfully! [LSM303 Wiring Diagram](https://www.pololu.com/product/2124)

In my shipment I also got a new ESP32 dev board I ran this sensor on. It has a
slightly different pinout from what I am used to with my other boards - a
helpful pinout description was found here: [New Dev Board
Pinout](https://lastminuteengineers.com/esp32-pinout-reference/)

# July 11 2025 - 3:30 p.m.
Today I received my parts from aliexpress. Well, most of them. I am eager to get
to work on them now, but for now I will set up this repo along with some devlogs
to keep track of my design progress.

Yesterday, I finished the most important proof of concept. I got high quality
320 kbps Mp3 files (A Morgan Wallen song) playing over bluetooth A2DP with Phil
Schatzmann's library. It's a work of art it's so simple. Now I am confident
every other piece will go smoothly as it all seems to be very common in the
maker world. New to me yes, but not exactly reinventing the wheel. Here's to the
excitement of building your own tools!!!

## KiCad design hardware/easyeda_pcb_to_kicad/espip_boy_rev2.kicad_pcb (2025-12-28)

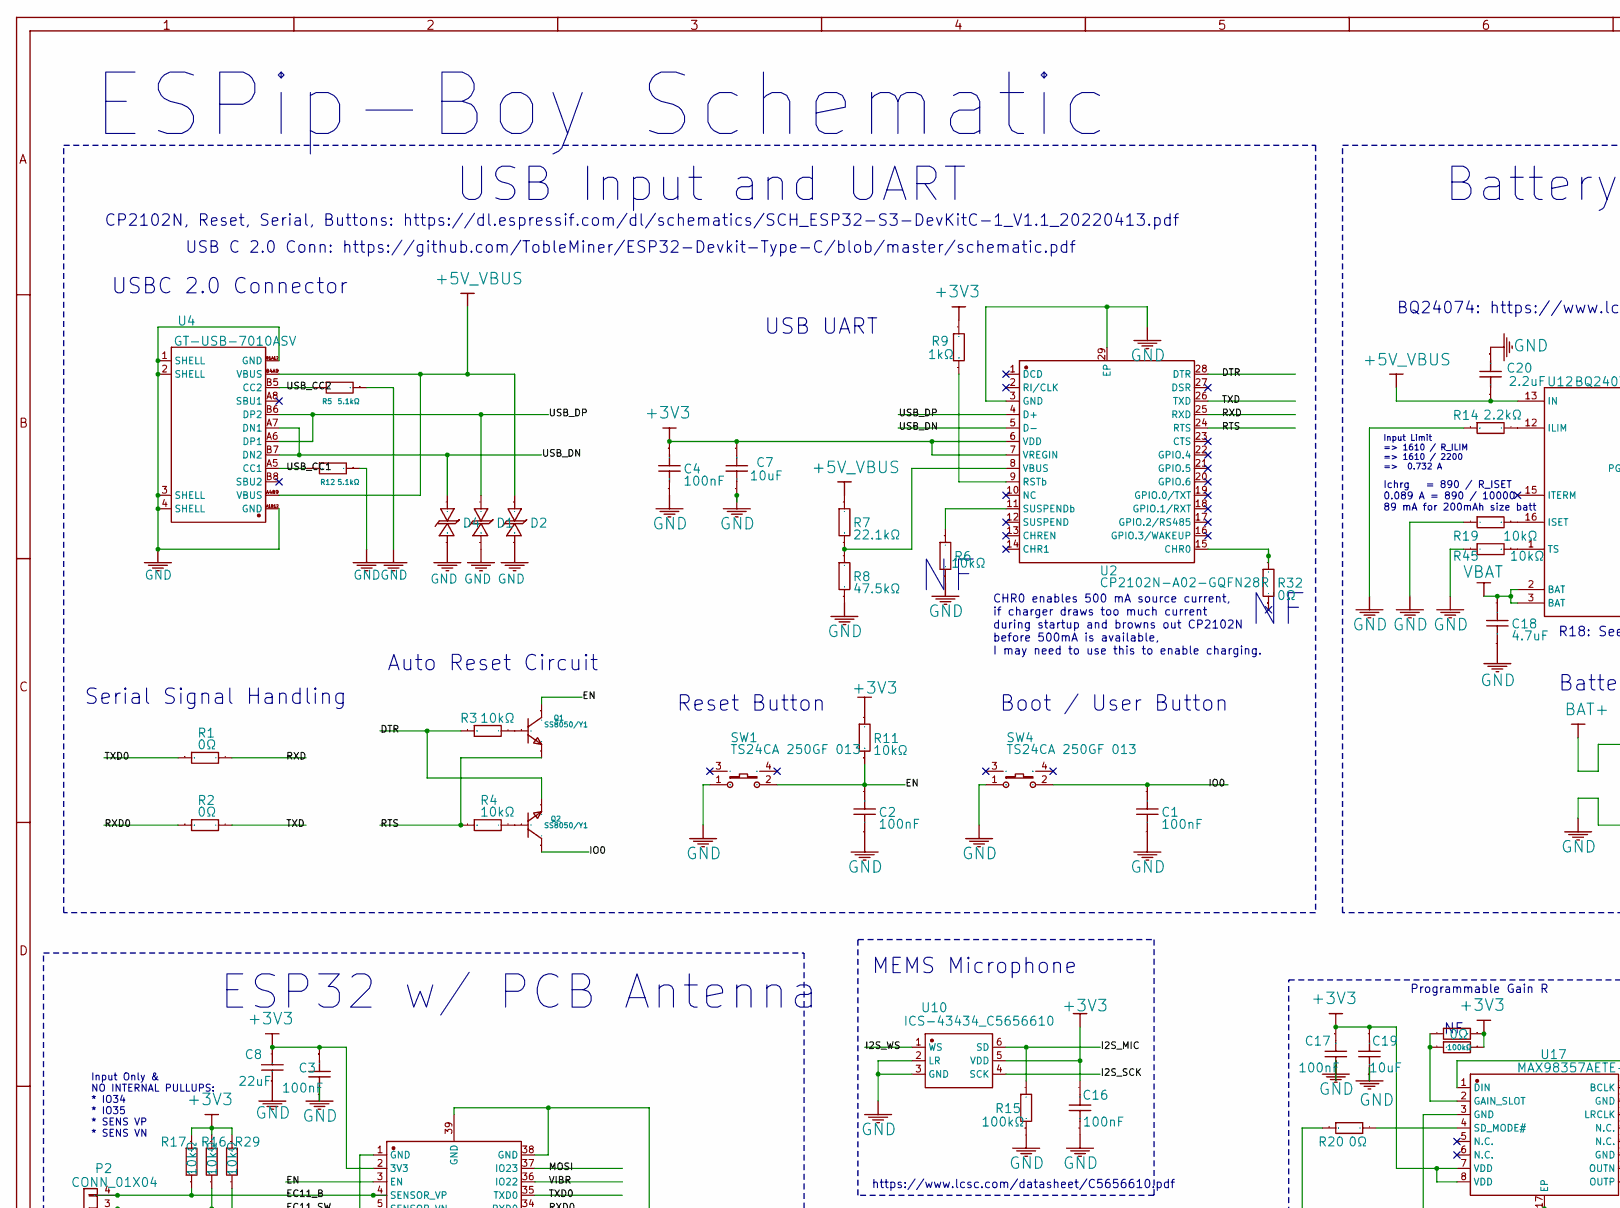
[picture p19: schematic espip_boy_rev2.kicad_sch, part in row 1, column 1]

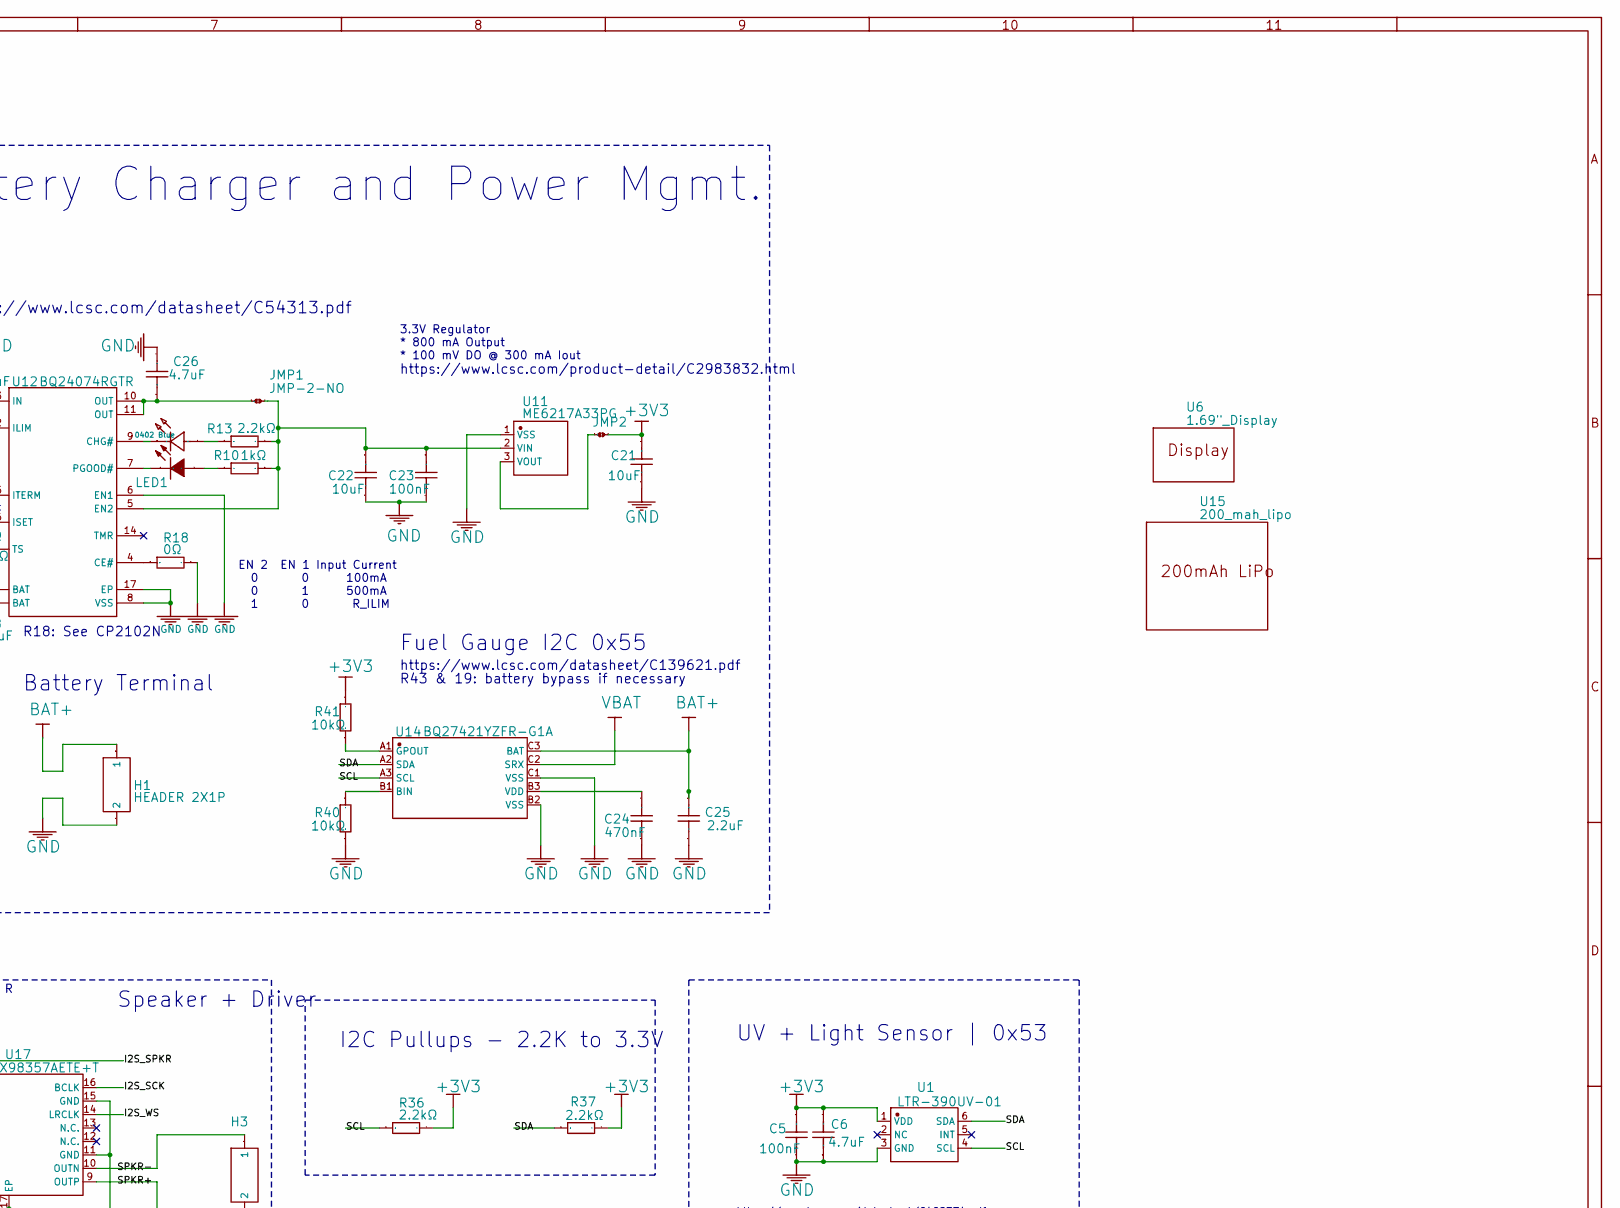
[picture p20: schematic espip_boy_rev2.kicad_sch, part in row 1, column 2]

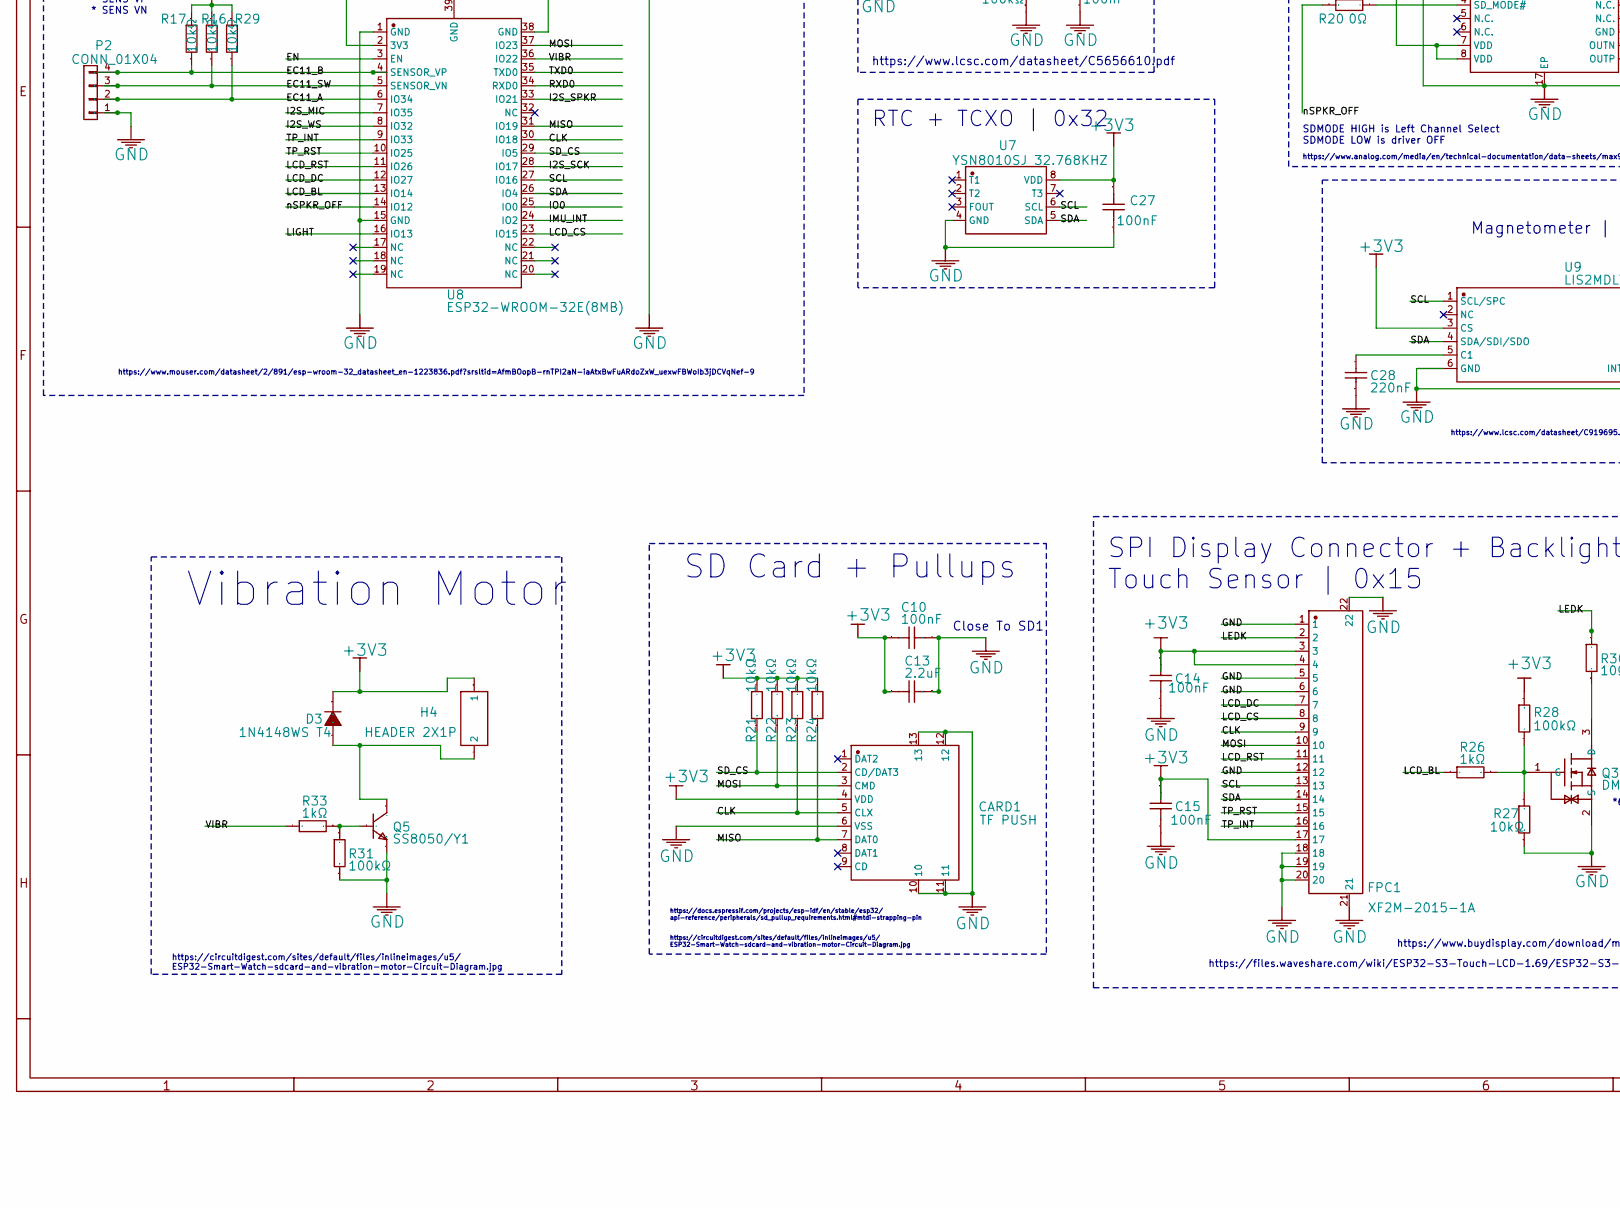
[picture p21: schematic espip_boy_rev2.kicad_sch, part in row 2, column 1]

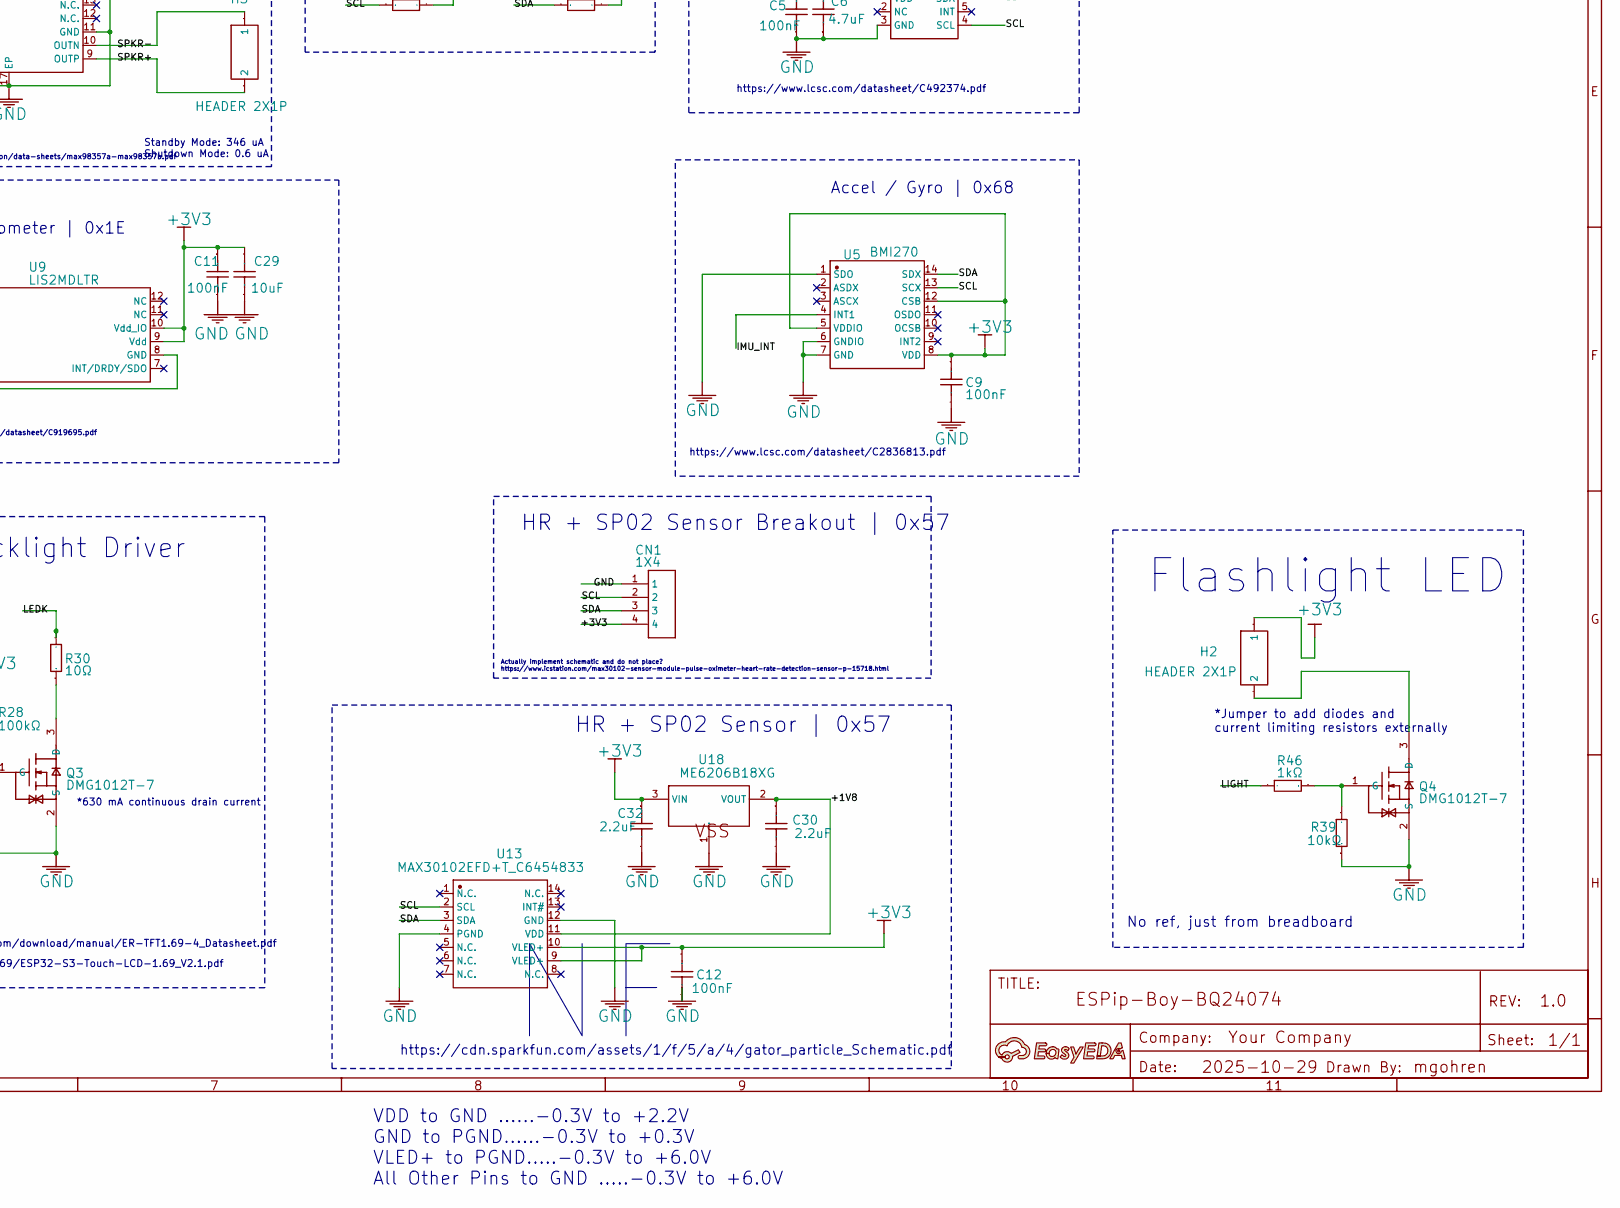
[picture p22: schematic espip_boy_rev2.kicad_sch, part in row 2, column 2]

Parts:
A1: A; SW-SMD_L4.7-W3.5-P3.35-EH; Manufacturer Part ?
C1, C2, C3, C4, C5, C9, C10, C11, C12, C14, C15, C16, C17, C23, C27: 100nF; C_0402_1005Metric; Manufacturer Part CL05B104KO5NNNC
C6, C18, C26: 4.7uF; C_0402_1005Metric; Manufacturer Part CL05A475KP5NRNC
C7, C19, C21, C22, C29: 10uF; C_0402_1005Metric; Manufacturer Part CL05A106MP5NUNC
C8: 22uF; C_0805_2012Metric; Manufacturer Part CL21A226MPQNNNE
C13, C20, C25, C30, C32: 2.2uF; C_0402_1005Metric; Manufacturer Part CL05A225KO5NQNC
C24: 470nF; C_0402_1005Metric; Manufacturer Part CL05A474KA5NNNC
C28: 220nF; C_0402_1005Metric; Manufacturer Part CL05B224KO5NNNC
CARD1: TF PUSH; TF-SMD_TF-PUSH; Manufacturer Part TF PUSH
CN1: 1X4
D1, D2, D4: LESD5D5.0CT1G_C5199850; D_SOD-523; Manufacturer Part LESD5D5.0CT1G
D3: 1N4148WS T4; Manufacturer Part 1N4148WS
FPC1: XF2M-2015-1A; FPC-SMD_20P-P0.50_XF2M-2015-1A; Manufacturer Part XF2M-2015-1A
H1, H2, H3, H4: HEADER 2X1P; Manufacturer Part None
JMP1, JMP2: JMP-2-NO
LED1: TZ-P2-0402YGTIA1-0.45T; LED_0402_1005Metric; Manufacturer Part TZ-P2-0402YGTIA1-0.45T
P2: CONN_01X04
Q1, Q2, Q5: SS8050/Y1; TSOT-23; Manufacturer Part SS8050/Y1
Q3, Q4: DMG1012T-7; SOT-523; Manufacturer Part DMG1012T-7
R1, R2, R18, R20, R32, R38: 0Ω; R_0402_1005Metric; Manufacturer Part 0402WGF0000TCE
R3, R4, R6, R11, R16, R17, R19, R21, R22, R23, R24, R27, R29, R39, R40, R41, R45: 10kΩ; R_0402_1005Metric; Manufacturer Part 0402WGF1002TCE
R5, R12: 5.1kΩ; R_0402_1005Metric; Manufacturer Part 0402WGF5101TCE
R7: 22.1kΩ; R_0402_1005Metric; Manufacturer Part 0402WGF2212TCE
R8: 47.5kΩ; R_0402_1005Metric; Manufacturer Part 0402WGF4752TCE
R9, R10, R26, R33, R46: 1kΩ; R_0402_1005Metric; Manufacturer Part 0402WGF1001TCE
R13, R14, R36, R37: 2.2kΩ; R_0402_1005Metric; Manufacturer Part 0402WGF2201TCE
R15, R28, R31, R35: 100kΩ; R_0402_1005Metric; Manufacturer Part 0402WGF1003TCE
R30: 10Ω; R_0402_1005Metric; Manufacturer Part 0402WGF100JTCE
SW1, SW4: TS24CA 250GF 013; SW-SMD_L4.7-W3.5-P3.35-EH; Manufacturer Part TS24CA 250gf 013
U1: LTR-390UV-01; SENSOR-SMD_LTR-390UV-01; Manufacturer Part LTR-390UV-01
U2: CP2102N-A02-GQFN28R; QFN-28-1EP_5x5mm_P0.5mm_EP3.35x3.35mm_ThermalVias; Manufacturer Part CP2102N-A02-GQFN28R
U3: 0402 Blue; LED_0402_1005Metric; Manufacturer Part XL-1005UBC
U4: GT-USB-7010ASV; USB-C-SMD_G-SWITCH_GT-USB-7010ASV; Manufacturer Part GT-USB-7010ASV
U5: BMI270; LGA-14_L3.0-W2.5-P0.50-BR; Manufacturer Part BMI270
U6: 1.69"_Display
U7: YSN8010SJ 32.768KHZ; SOP-8_L4.9-W3.9-P1.27-LS6.0-BL; Manufacturer Part YSN8010SJ 32.768KHZ
U8: ESP32-WROOM-32E(8MB); ESP32-WROOM-32E; Manufacturer Part ESP32-WROOM-32E-N8
U9: LIS2MDLTR; LGA-12_L2.0-W2.0-P0.50-BL; Manufacturer Part LIS2MDLTR
U10: ICS-43434_C5656610; MIC-SMD_6P-L3.5-W2.7-P0.90-BL; Manufacturer Part ICS-43434
U11: ME6217A33PG; SOT-89-3; Manufacturer Part ME6217A33PG
U12: BQ24074RGTR; TQFN-16_L3.0-W3.0-P0.50-BL-EP1.5; Manufacturer Part BQ24074RGTR
U13: MAX30102EFD+T_C6454833; OESIP-14_L5.6-W3.3-P0.80-TL; Manufacturer Part MAX30102EFD+T
U14: BQ27421YZFR-G1A; DSBGA-9_L1.5-W1.5-R3-C3-P0.50-BL; Manufacturer Part BQ27421YZFR-G1A
U15: 200_mah_lipo
U17: MAX98357AETE+T; TQFN-16_L3.0-W3.0-P0.50-BL-EP1.5; Manufacturer Part MAX98357AETE+T
U18: ME6206B18XG; TSOT-23; Manufacturer Part ME6206B18XG

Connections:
+3V3: C3.1, C4.1, C5.1, C6.2, C7.1, C8.2, C9.1, C10.1, C11.1, C12.1, C13.2, C14.1, C15.1, C16.2, C17.1, C19.2, C21.1, C27.1, C29.2, C32.1, CARD1.4 (VDD), CN1.4, D3.1 (K), FPC1.3, FPC1.4, FPC1.17, H2.1, H4.1, JMP2.2, R9.2, R11.2, R16.1, R17.1, R21.2, R22.2, R23.2, R24.2, R28.1, R29.1, R35.1, R36.2, R37.2, R38.1, R41.2, U1.1 (VDD), U2.6 (VDD), U2.7 (VREGIN), U5.5 (VDDIO), U5.8 (VDD), U5.12 (CSB), U7.8 (VDD), U8.2 (3V3), U9.3 (CS), U9.9 (Vdd), U9.10 (Vdd_IO), U10.5 (VDD), U13.9 (VLED+), U13.10 (VLED+), U17.7 (VDD), U17.8 (VDD), U18.3 (VIN)
+5V_VBUS: C20.2, D2.2, R7.2, U4.A4B9 (VBUS), U4.B4A9 (VBUS), U12.13 (IN)
/+1V8: C30.1, U13.11 (VDD), U18.2 (VOUT)
/CLK: CARD1.5 (CLX), FPC1.9, R23.1, U8.30 (IO18)
/DTR: Q2.2 (E), R3.1, U2.28 (DTR)
/EC11_A: P2.2, R29.2, U8.6 (IO34)
/EC11_B: P2.4, R17.2, U8.4 (SENSOR_VP)
/EC11_SW: P2.3, R16.2, U8.5 (SENSOR_VN)
/EN: C2.1, Q1.3 (C), R11.1, SW1.2, U8.3 (EN)
/I2S_MIC: R15.2, U8.7 (IO35), U10.6 (SD)
/I2S_SCK: U8.28 (IO17), U10.4 (SCK), U17.16 (BCLK)
/I2S_SPKR: U8.33 (IO21), U17.1 (DIN)
/I2S_WS: U8.8 (IO32), U10.1 (WS), U17.14 (LRCLK)
/IMU_INT: U5.4 (INT1), U8.24 (IO2)
/IO0: C1.1, Q2.3 (C), SW4.2, U8.25 (IO0)
/LCD_BL: R26.2, U8.13 (IO14)
/LCD_CS: FPC1.8, U8.23 (IO15)
/LCD_DC: FPC1.7, U8.12 (IO27)
/LCD_RST: FPC1.11, U8.11 (IO26)
/LEDK: FPC1.2, R30.2
/LIGHT: R46.2, U8.16 (IO13)
/MISO: CARD1.7 (DAT0), R24.1, U8.31 (IO19)
/MOSI: CARD1.3 (CMD), FPC1.10, R22.1, U8.37 (IO23)
/RTS: Q1.2 (E), R4.1, U2.24 (RTS)
/RXD: R1.2, U2.25 (RXD)
/RXD0: R2.1, U8.34 (RXD0)
/SCL: CN1.2, FPC1.13, R36.1, U1.4 (SCL), U5.13 (SCX), U7.6 (SCL), U8.27 (IO16), U9.1 (SCL/SPC), U13.2 (SCL), U14.A3 (SCL)
/SDA: CN1.3, FPC1.14, R37.1, U1.6 (SDA), U5.14 (SDX), U7.5 (SDA), U8.26 (IO4), U9.4 (SDA/SDI/SDO), U13.3 (SDA), U14.A2 (SDA)
/SD_CS: CARD1.2 (CD/DAT3), R21.1, U8.29 (IO5)
/SPKR+: H3.2, U17.9 (OUTP)
/SPKR-: H3.1, U17.10 (OUTN)
/TP_INT: FPC1.16, U8.9 (IO33)
/TP_RST: FPC1.15, U8.10 (IO25)
/TXD: R2.2, U2.26 (TXD)
/TXD0: R1.1, U8.35 (TXD0)
/USB_CC1: R12.2, U4.A5 (CC1)
/USB_CC2: R5.2, U4.B5 (CC2)
/USB_DN: D4.2, U2.5 (D-), U4.A7 (DN1), U4.B7 (DN2)
/USB_DP: D1.2, U2.4 (D+), U4.A6 (DP1), U4.B6 (DP2)
/VIBR: R33.2, U8.36 (IO22)
/nSPKR_OFF: R20.1, U8.14 (IO12)
BAT+: C25.1, H1.1, U14.C3 (BAT)
GND: C1.2, C2.2, C3.2, C4.2, C5.2, C6.1, C7.2, C8.1, C9.2, C10.2, C11.2, C12.2, C13.1, C14.2, C15.2, C16.1, C17.2, C18.1, C19.1, C20.1, C21.2, C22.2, C23.2, C24.1, C25.2, C26.2, C27.2, C28.1, C29.1, C30.2, C32.2, CARD1.6 (VSS), CARD1.10, CARD1.11, CARD1.12, CARD1.13, CN1.1, D1.1, D2.1, D4.1, FPC1.1, FPC1.5, FPC1.6, FPC1.12, FPC1.18, FPC1.19, FPC1.20, FPC1.21, FPC1.22, H1.2, P2.1, Q3.2 (S), Q4.2 (S), Q5.2 (E), R5.1, R6.1, R8.1, R12.1, R14.1, R15.1, R18.2, R19.2, R27.1, R31.1, R39.1, R40.1, R45.2, SW1.1, SW4.1, U1.3 (GND), U2.3 (GND), U2.29 (EP), U4.1 (SHELL), U4.2 (SHELL), U4.3 (SHELL), U4.4 (SHELL), U4.A1B12 (GND), U4.B1A12 (GND), U5.1 (SDO), U5.6 (GNDIO), U5.7 (GND), U7.4 (GND), U8.1 (GND), U8.15 (GND), U8.38 (GND), U8.39 (GND), U9.6 (GND), U9.8 (GND), U10.2 (LR), U10.3 (GND), U11.1 (VSS), U12.6 (EN1), U12.8 (VSS), U12.17 (EP), U13.4 (PGND), U13.12 (GND), U14.B2 (VSS), U14.C1 (VSS), U17.3 (GND), U17.11 (GND), U17.15 (GND), U17.17 (EP), U18.1 (VSS)
unnamed: C26.1, JMP1.1, U12.10 (OUT), U12.11 (OUT)
unnamed: D3.2 (A), H4.2, Q5.3 (C)
unnamed: LED1.2, R10.2
unnamed: Q1.1 (B), R3.2
unnamed: Q2.1 (B), R4.2
unnamed: Q3.3 (D), R30.1
unnamed: Q3.1 (G), R26.1, R27.2, R28.2
unnamed: H2.2, Q4.3 (D)
unnamed: Q4.1 (G), R39.2, R46.1
unnamed: Q5.1 (B), R31.2, R33.1
unnamed: R32.2, U2.15 (CHR0)
unnamed: R9.1, U2.9 (RSTb)
unnamed: R6.2, U2.11 (SUSPENDb)
unnamed: R7.1, R8.2, U2.8 (VBUS)
unnamed: R13.1, U3.2 (A)
unnamed: C28.2, U9.5 (C1)
unnamed: C22.1, C23.1, JMP1.2, R10.1, R13.2, U11.2 (VIN), U12.5 (EN2)
unnamed: JMP2.1, U11.3 (VOUT)
unnamed: R18.1, U12.4 (CE#)
unnamed: U3.1 (K), U12.9 (CHG#)
unnamed: R14.2, U12.12 (ILIM)
unnamed: R19.1, U12.16 (ISET)
unnamed: LED1.1, U12.7 (PGOOD#)
unnamed: R45.1, U12.1 (TS)
unnamed: R40.2, U14.B1 (BIN)
unnamed: R41.1, U14.A1 (GPOUT)
unnamed: C24.2, U14.B3 (VDD)
unnamed: R35.2, R38.2, U17.2 (GAIN_SLOT)
unnamed: R20.2, U17.4 (SD_MODE#)
VBAT: C18.2, U12.2 (BAT), U12.3 (BAT), U14.C2 (SRX)

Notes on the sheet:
HR + SP02 Sensor | 0x57
SPI Display Connector + Backlight Driver Touch Sensor | 0x15
Programmable Gain R
SD Card + Pullups
Battery Terminal
RTC + TCXO | 0x32
Accel / Gyro | 0x68
https://www.analog.com/media/en/technical-documentation/data-sheets/max98357a-max98357b.pdf
Input Only & NO INTERNAL PULLUPS: * IO34 * IO35 * SENS VP * SENS VN
MEMS Microphone
I2C Pullups - 2.2K to 3.3V
Magnetometer | 0x1E
USBC 2.0 Connector
https://www.lcsc.com/datasheet/C5656610.pdf
Auto Reset Circuit
Close To SD1
Boot / User Button
https://files.waveshare.com/wiki/ESP32-S3-Touch-LCD-1.69/ESP32-S3-Touch-LCD-1.69_V2.1.pdf
CP2102N, Reset, Serial, Buttons: https://dl.espressif.com/dl/schematics/SCH_ESP32-S3-DevKitC-1_V1.1_20220413.pdf
*Jumper to add diodes and current limiting resistors externally
https://www.lcsc.com/datasheet/C139621.pdf
R43 & 19: battery bypass if necessary
https://www.lcsc.com/datasheet/C492374.pdf
EN 2 EN 1 Input Current 0 0 100mA 0 1 500mA 1 0 R_ILIM
Fuel Gauge I2C 0x55
Actually implement schematic and do not place? https://www.icstation.com/max30102-sensor-module-pulse-oximeter-heart-rate-detection-sensor-p-15718.html
Flashlight LED
https://www.mouser.com/datasheet/2/891/esp-wroom-32_datasheet_en-1223836.pdf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
USB UART
Input Limit => 1610 / R_ILIM => 1610 / 2200 => 0.732 A
ESPip-Boy Schematic
https://www.buydisplay.com/download/manual/ER-TFT1.69-4_Datasheet.pdf
Battery Charger and Power Mgmt.
3.3V Regulator * 800 mA Output * 100 mV DO @ 300 mA Iout
*630 mA continuous drain current
VDD to GND ......-0.3V to +2.2V GND to PGND......-0.3V to +0.3V VLED+ to PGND.....-0.3V to +6.0V All Other Pins to GND .....-0.3V to +6.0V
No ref, just from breadboard
https://cdn.sparkfun.com/assets/1/f/5/a/4/gator_particle_Schematic.pdf
UV + Light Sensor | 0x53
SDMODE HIGH is Left Channel Select SDMODE LOW is driver OFF

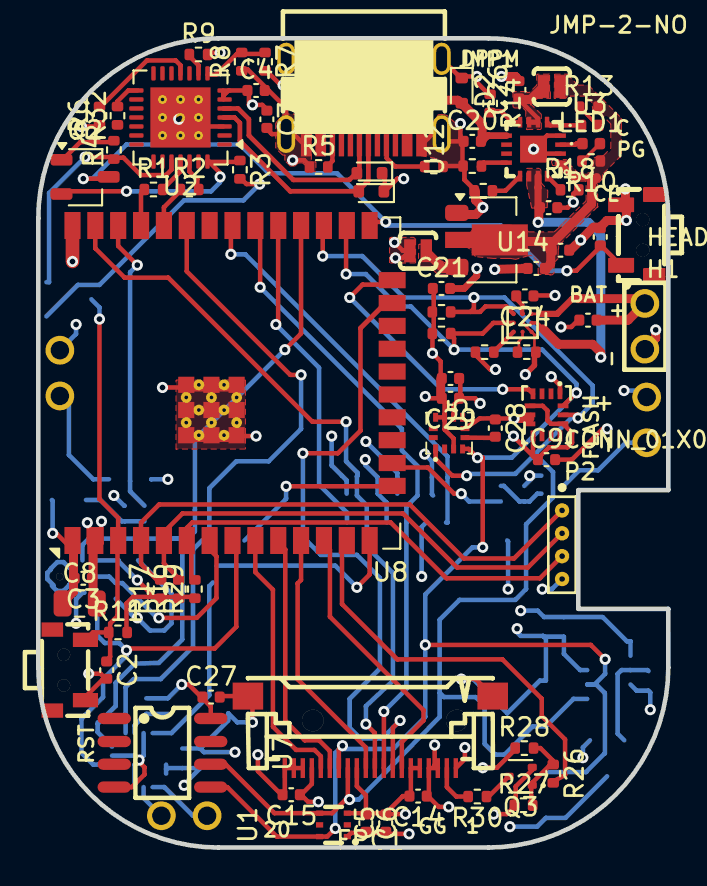
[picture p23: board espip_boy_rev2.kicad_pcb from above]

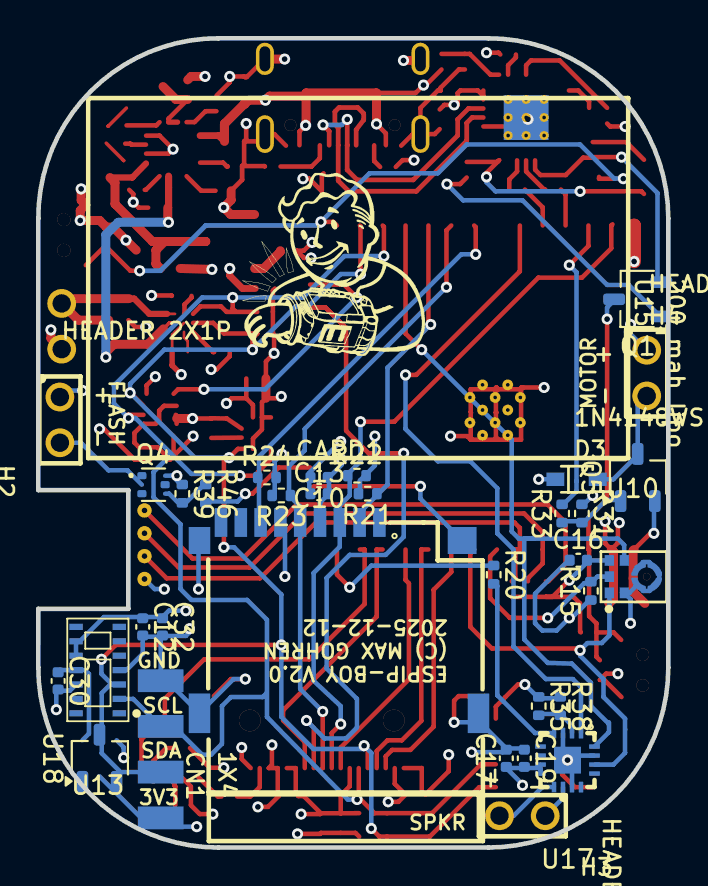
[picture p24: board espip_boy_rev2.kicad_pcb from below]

Board: 4 copper layers, 35.0 x 45.0 mm, 111 parts (34 on the bottom side), 73 nets.

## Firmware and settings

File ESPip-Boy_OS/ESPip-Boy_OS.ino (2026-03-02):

#include "log.h"
#include <Wire.h>
#include "freertos/FreeRTOS.h"
#include "freertos/task.h"

#include "pinout.h"
#include "clock.h"
#include "imu.h"
#include "display.h"
#include "sleep.h"
#include "fuel.h"
#include "rtc.h"
#include "termiwatch.h"
#include "flash.h"
#include "touch.h"
#include "weather.h"
#include "task_monitor.h"

void setup(void)
{
  DEBUG_BEGIN(115200);
  Wire.begin(IIC_SDA, IIC_SCL);

  init_clock();

  init_touch();

  init_weather_service();

  // Init Display ui
  init_termiwatch();

  // Display backlight control - turn on at bootup after ui in init
  init_display();

  imu_init();

  // Setup fuel gauge
  fuelGauge.begin(4, 16);
  //fuelGauge.configureBattery(); Only really needs to be done once

  init_flashlight();
  
  init_task_monitor();

  DEBUG_PRINTLN("ESPip-Boy init complete.");
}


void loop()
{
  handle_watch_orientation();
  handle_flashlight();
  handle_touch();
  
  vTaskDelay(pdMS_TO_TICKS(10)); // allow scheduler some breathing room
}

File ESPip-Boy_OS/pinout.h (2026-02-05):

#pragma once

// ----- Pin Definitions -----
#define LCD_DC     27
#define LCD_RST    26
#define LCD_CS     15
#define LCD_SCK    18
#define LCD_BL     14
#define LCD_MOSI   23

#define IIC_SDA    4
#define IIC_SCL    16

#define TP_RST     25
#define TP_INT     33

#define IMU_INT 2

#define BL_PIN 14

#define LED_PIN 13

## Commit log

2025-07-16 Started the PCB schematic!
2025-08-02 Starting August off with some more PCB design: adding connections to my USB Serial chip!
2025-08-17 EC11 schematic done, looking into batteries and associated ICs now
2025-08-27 Headphones test with bluetooth. Researching antenna performance and PMICs
2025-08-27 antenna and usbc reading/resources devlog
2025-08-29 TRAIN KEEPS ROLLING! USBC CONNECTOR DONE ON SCHEMATIC!
2025-09-03 Schematic time
2025-09-09 Waiting for power hardware, working on LVGL graphics now
2025-09-13 Update September2025-SchematicTime.md
    Added video
2025-09-26 Fuel gauge test and nearing completion of prototype!
2025-10-04 Cleaned up schematic to update with recent prototype changes
2025-10-08 Regulator and fuel gauge finished on the schematic
2025-10-09 Schematic is roughly complete.
2025-10-13 Simulated simple NPN flashlight LED driver
2025-10-17 Flashlight driver added to schematic
2025-10-21 LED Flashlight PWM driver - 20mA is so bright
    >
2025-10-22 Got the LED driver working perfectly
2025-10-23 Some final hardware validations before moving onto the first round of PCB design
2025-10-24 Flashlight driver devlog
2025-10-29 Finshed V1.0 of the PCB. Time to check it over, order and cross my fingers!
2025-10-30 V1.0 of PCB complete!
2025-11-06 USB diff. pair and added MAX30102 footprint. Cleaning up BOM. Need replacement I2S mic
2025-11-30 Renamed firmware source. Added case files
    [assem_no_encoder.FCStd, assem_with_encoder.FCStd, assem_with_encoder.step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]
2025-12-09 Clean up project, clean up kicad sch, learned split in FreeCAD for clamshell case design improvement
    [ESPip-Boy_V2.0.kicad_pcb, ESPip-Boy_V2.0.kicad_sch, assem_with_encoder.FCStd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]
2025-12-11 Placed some more components for V2.0
    [ESPip-Boy_V2.0.kicad_pcb]
2025-12-13 V2.0 finished. All hardware verified, only motor and microphone not working as expected
    [ESPip-Boy_V2.0.kicad_pcb, ESPip-Boy_V2.0.kicad_sch, display_espip-boy.FCStd]
2025-12-18 Penultimate? review of Rev2 pcb. Interfaced with more I2C devices to confirm working state
2025-12-20 Ordered Rev2 PCB
2025-12-27 Imported ESPip-Boy Rev2 pcb into KiCAD to get .STEP export
    [ESPip-Boy_V2.0.kicad_pcb, ESPip-Boy_V2.0.kicad_sch, display_espip-boy.FCStd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]
2025-12-28 Completed assembly of Rev 2 pcb, battery, display and digital crown
    [BackupProjects_mgohren_personal_1_20251228.kicad_pcb, BackupProjects_mgohren_personal_1_20251228.kicad_sch, BackupProjects_mgohren_personal_1_20251228.step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]
2025-12-30 Rev2 assembled and working
2025-12-31 Goofy case design sent to print shop
2026-01-02 Sent 20mm lug split case with M1.2 screw holes to printer
    [case_less_pcb_components.FCStd, case_slice_in_half_test.FCStd, case_v2.FCStd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]
2026-01-14 Add battery configuration to 200mAh, add todos for even deeper sleep
2026-01-14 Case complete, spicing up the UI with LVGL and EEZ Studio
2026-01-15 Fixed RTC and wake logic to update time from RTC after 0th boot which updates from WiFi
    [ESPip-Boy_OS.ino, flash.ino, rtc.ino]
2026-01-16 Cleaned up IMU logic, decoupled screen sleep from esp32 sleep, started implementing pwm for led and bl but not finished yet
2026-01-16 Added display backlight fading in and out! Now to fix LED
    [ESPip-Boy_OS.ino]
2026-01-16 Got flashlight fade in working with button press
2026-01-19 Added low power mode for IMU. Moved source into .cpp files to solve circular include problem of header only implementations
    [ESPip-Boy_OS.ino, display.cpp, imu.cpp]
2026-02-05 Fixed display with correct offset. Added double tap to turn on flashlight
    [ESPip-Boy_OS.ino, display.cpp, flash.cpp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]
2026-02-13 Refactored lots of header only implementations into classes with global extern instance.
    Also added rough weather update with API and task to update. Currently updates every 15 hours and returns closest forecast data. Need to clean up and add WiFi mutex, possibly batch together with star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
2026-02-18 Updated knob and added stls for printing
    [case_less_pcb_components.stl, encoder_knob_espip-boy-Body004.stl, encoder_knob_espip-boy.FCStd]
2026-03-02 Added task monitor task. Added debug print calls.
2026-03-02 Replaced all serial commands with debug commands
    [ESPip-Boy_OS.ino, display.cpp, flash.cpp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]
2026-03-03 Lower imu polling rate to save battery
2026-03-29 Add new case V3 with covered antenna and compliant IO0 button. Early return from weather service until wifi manager is implemented
    [V1_case.FCStd, V2_case.FCStd, V3_case.FCStd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]
